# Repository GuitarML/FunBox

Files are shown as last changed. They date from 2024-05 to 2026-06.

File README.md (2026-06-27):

# Funbox


Funbox is a digital stereo guitar effect platform using the Daisy Seed by Electrosmith.
This repo includes the KiCad design files for the PCB, as well as software packages to configure your
Funbox as a fully featured guitar pedal. You can build your own and use the effects included here,
or use it as a starting place to design your own awesome pedal!

Video Demos on YouTube:

[Mars Amp Sim/Delay](https://youtu.be/e60Wy_VvJX8?si=AbR1MXqZ35HZ0Mvu), [Jupiter Reverb Shaper](https://youtu.be/iQnR0dN56QY?si=inZRtJW6ivPTOBN7),
[Neptune Reverb/Delay](https://youtu.be/nuLmwTXF1v8?si=5k8mRED5zVJWO6t1), [Pluto Dual Looper](https://youtu.be/xCFR0EeIMSg?si=6pakTC9j9leRP9t6),
[Venus Spectral Reverb](https://youtu.be/IHFEQsWR4W4?si=BbFsI6RXE-6vq7Sy), [Saturn Spectral Delay](https://youtu.be/adQQrBSwXU4?si=lk55HOxCmDiPBn_s),
[MidiKeys Synth](https://youtu.be/qRBMoK8jLx0?si=yauST03D38Y4MzrH), [Mercury Amp Emulator](https://youtu.be/-yD2pLMCNi4?si=rLxFXH2HT4IHW6-g),
[Earth Plate Reverb/Octave](https://youtu.be/5oxMYXyyZHo?si=3_w1OVgaGqCgooyH) [Uranus Granular Delay and Synth](https://youtu.be/lxxZvYDoElI?si=sbfe8fWKY_A6ajux)

Read the [Funbox Build Guide](https://medium.com/@keyth72/funbox-build-guide-afbd8046121e) for a step by step on ordering parts, soldering and assembling the pcb and hardware, and uploading programs to the Funbox.

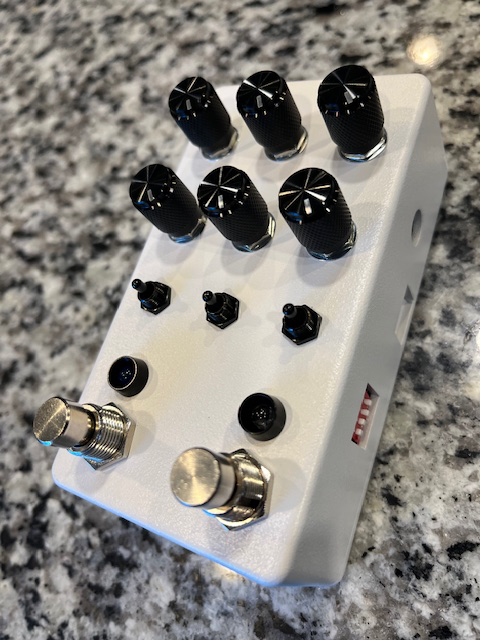
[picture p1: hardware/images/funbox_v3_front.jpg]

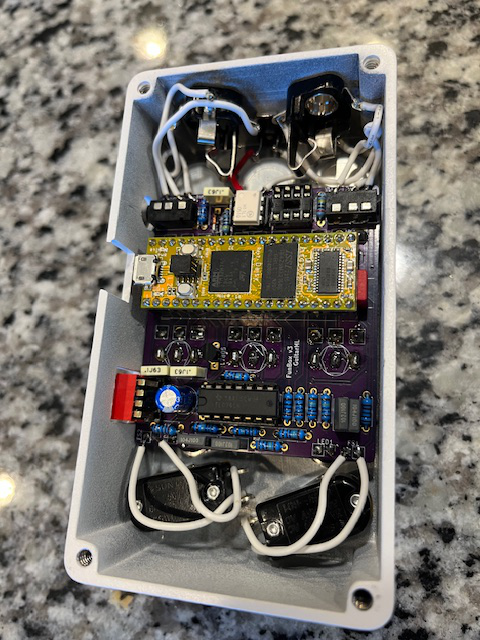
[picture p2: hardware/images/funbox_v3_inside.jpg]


The resources included here allow you to build a guitar pedal with comparable features to commercial brands. 
Soldering is required to build the hardware. Tayda drill templates are linked along with an Adobe Illustrator 
template for UV printing the enclosure, if desired. 

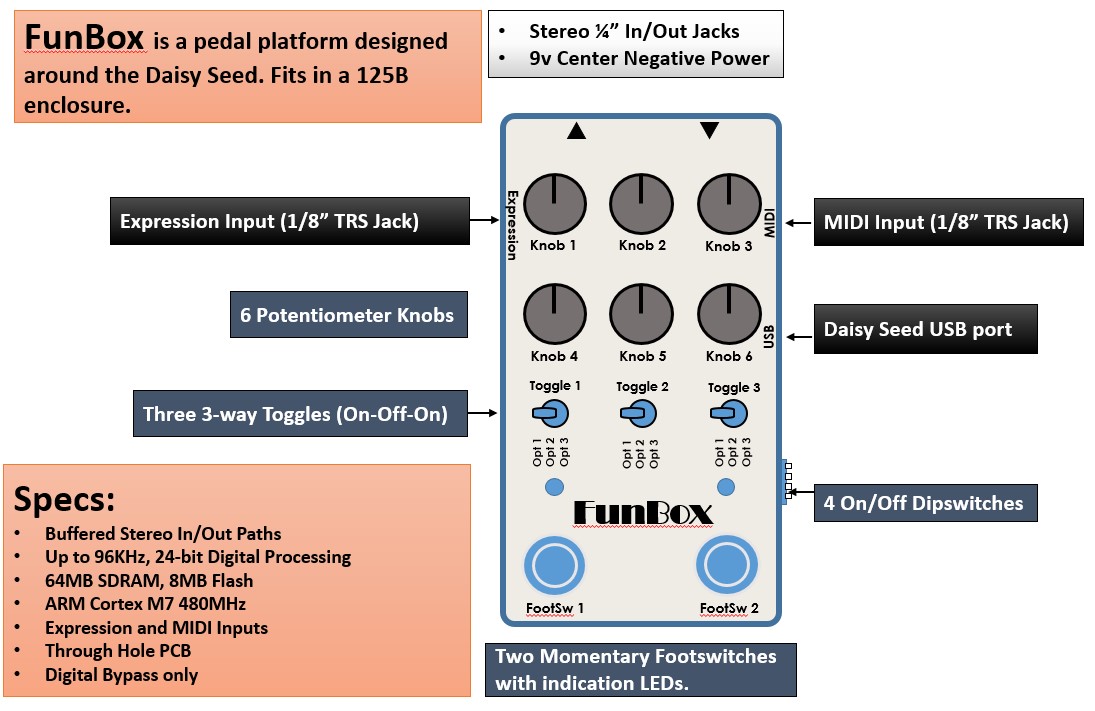
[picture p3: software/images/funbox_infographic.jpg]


## Hardware

The Funbox pedal consists of the following main components:

 - Daisy Seed (order from [Electro-Smith](https://www.electro-smith.com/)) - $30
 - Funbox PCB (order from OSHPark or other manufacturer) - $30 for minimum of 3 from OshPark
 - 125B Enclosure ([Powder coat](https://www.taydaelectronics.com/cream-125b-style-aluminum-diecast-enclosure.html), [Custom Drill](https://www.taydaelectronics.com/125b-custom-drill-enclosure-service.html), and [UV print](https://www.taydaelectronics.com/125b-uv-printing-service.html) ordered from [Tayda](https://www.taydaelectronics.com/)) - $15
 - Electronic Components (Tayda, Mouser, Amazon, Digikey (for Dipswitches) etc.)
 - Hardware Components for Funbox (1/4" Stereo Audio Jacks, Power Jack, Knobs, Switches) (I like [LoveMySwitches](https://lovemyswitches.com/))
 - "Funbox" Software - Build your own binary from this repo or download .bin from the [Releases page](https://github.com/GuitarML/FunBox/releases)
<br><br>
There are alot of variables in building your own pedal, but typically the Funbox will cost around $120 to $150 to build.

IMPORTANT: If you use the Drill Template, double check that the hole diameters match your components. Especially for the LED's, which use the larger diameter hole for 5mm [LED Bezel](https://lovemyswitches.com/5mm-chrome-metal-led-bezel-bag-of-5/).

The PCB design KiCad is provided [here](https://github.com/GuitarML/Funbox/blob/main/hardware/funbox_v3_midi_exp), which can be used to order from a manufacturer such as OSHPark or PCBWay.<br>
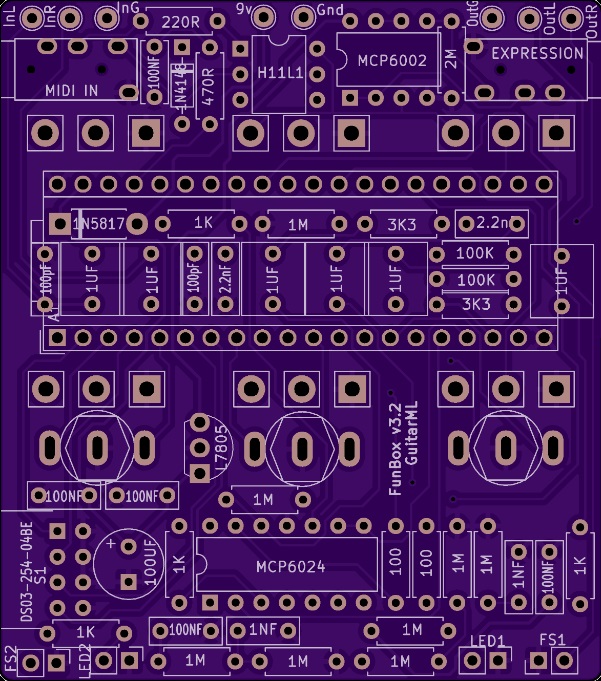
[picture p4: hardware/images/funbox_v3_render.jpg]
<br>
Component values are printed on the board for easy assembly! (OSHPark render shown here)

## Software

The following pedal modules are provided here:

Planet Series
- [Mercury](https://github.com/GuitarML/Mercury): An amp emulator running NAM Neural Amp Modeler and a 4 band EQ.
- [Venus](https://github.com/GuitarML/Funbox/blob/main/software/Venus): A Spectral Reverb using a FFT to create shimmery, ethereal soundscapes.
- [Earth](https://github.com/GuitarML/Earth): A Plate Reverb with octave and overdrive effects.
- [Mars](https://github.com/GuitarML/Funbox/blob/main/software/Mars): An amp sim/delay using neural models and Impulse Responses and three delay modes.
- [Jupiter](https://github.com/GuitarML/Funbox/blob/main/software/Jupiter): A Reverb with a focus on EQ for shaping the sound.
- [Saturn](https://github.com/GuitarML/Funbox/blob/main/software/Saturn): A Spectral delay using a FFT to delay different frequencies individually.
- [Uranus](https://github.com/GuitarML/Funbox/blob/main/software/Uranus): A granular delay and FM synth.
- [Neptune](https://github.com/GuitarML/Funbox/blob/main/software/Neptune): A Reverb/Delay capable of ethereal sounds.
- [Pluto](https://github.com/GuitarML/Funbox/blob/main/software/Pluto): A Dual/Stereo looper with variable speed/direction control and real time loop effects.

There are also a couple [Experiments](https://github.com/GuitarML/Funbox/blob/main/software/Experiments) including a Chorus/Reverb and FFT based filter.

Download the compiled modules for the Funbox from the [Releases Page](https://github.com/GuitarML/FunBox/releases).

### Build the Software
Head to the [Electro-Smith Wiki](https://github.com/electro-smith/DaisyWiki) to learn how to set up the Daisy environment on your computer.

```
# Clone the repository
$ git clone https://github.com/GuitarML/Funbox.git
$ cd Funbox

# initialize and set up submodules
$ git submodule update --init --recursive

# Build the daisy libraries (after installing the Daisy Toolchain):
# Replace the daisy_petal files in libDaisy/src with the files in the "mod" directory to properly map controls on Funbox.
$ make -C libDaisy
$ make -C DaisySP

# Build the desired pedal firmware (Mars pedal shown below as example) (after installing the Daisy Toolchain)
$ cd software/Mars
$ make
```

Then upload the firmware (.bin) to your Funbox pedal with the following commands (or use the [Electrosmith Web Programmer](https://electro-smith.github.io/Programmer/))
```
# This is the procedure for uploading to Flash memory on the Daisy Seed, if using SRAM memory use Bootloader method (Mars and Neptune use SRAM).
cd your_pedal
# using USB (after entering bootloader mode)
make program-dfu
# using JTAG/SWD adaptor (like STLink)
make program
```

To upload your firmware to SRAM (more memory available here for larger programs), see the [libdaisy Bootloader Reference](https://electro-smith.github.io/libDaisy/md_doc_2md_2__a7___getting-_started-_daisy-_bootloader.html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)
or use the [Electrosmith Web Programmer](https://electro-smith.github.io/Programmer/)

To use the Electrosmith Web Programmer to upload programs to SRAM (480KB available instead of 128KB in Flash), do this:
1. Connect to the Daisy Seed as normal from the [Electrosmith Web Programmer](https://electro-smith.github.io/Programmer/).
2. Click "Advanced" button at the bottom, and click "Flash Bootloader Image".
3. On the Daisy Seed, press the RESET button (LED should be lit), and then quickly press the BOOT button. The BOOT LED should now be pulsing.
4. Back in the Web Programmer, choose your .bin file from the "Choose File" button, and then click the "Program" button to upload to SRAM.
5. To load a program back to Flash after using the Bootloader, do the normal upload procedure to overwrite the Bootloader with your new program.

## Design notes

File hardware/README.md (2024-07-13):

# Hardware

This directory contains the KiCad files for manufacturing the Funbox PCB. Includes schematic, pcb, and generated BOM.
Funbox uses a 125B sized enclosure.

## Funbox v1

VERIFIED WORKING - using OshPark standard board manufacturing

Funbox v1 uses a 125B enclosure with the following features:
- Stereo In/Out
- 9v power
- 6 potentiometer knobs 
- 3 3-way switches On-Off-On
- 2 SPST momentary footswitches
- 2 LEDs
- 2 Dipswitches

[Tayda Drill Template](https://drill.taydakits.com/box-designs/new?public_key=bXVVdnZXK0pOVWJjZG5YOGtwd282Zz09Cg==)

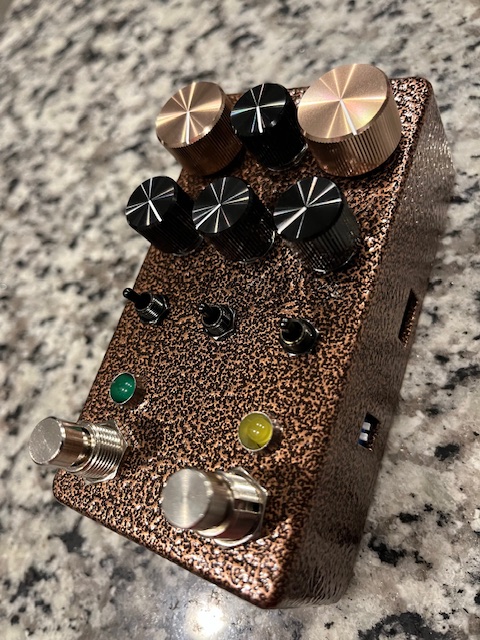
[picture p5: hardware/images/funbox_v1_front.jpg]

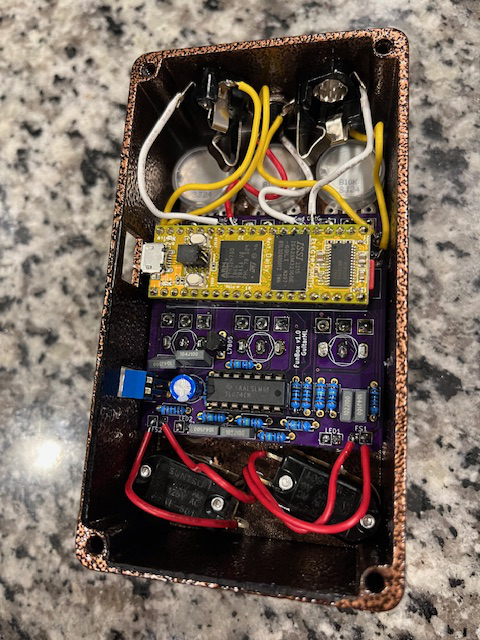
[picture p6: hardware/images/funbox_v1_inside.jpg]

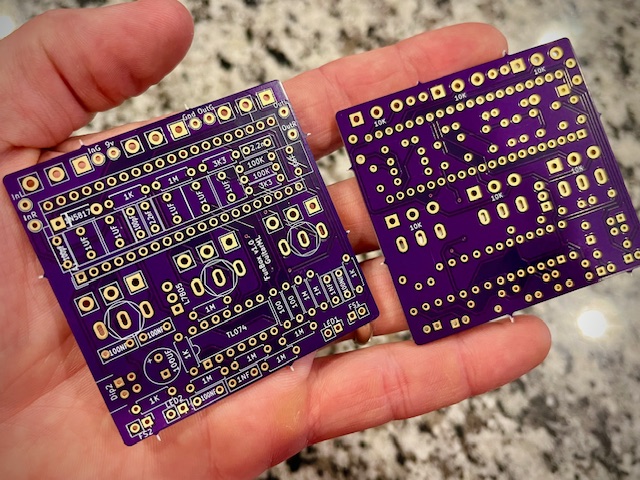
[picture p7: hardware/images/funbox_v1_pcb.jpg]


## Funbox v2

Funbox v2 adds MIDI In/Out via two 1/8" TRS jacks and up to a 4 dip switch array, instead of 2.

[Tayda Drill Template](https://drill.taydakits.com/box-designs/new?public_key=M3BDZTdRSmFWRkF4QXpQUzRORjIwQT09Cg==)

CURRENTLY UNTESTED 

## Funbox v3.2

Funbox v3 replaces the MIDI out jack from version 2 with an Expression Input jack. 
Version 3.2 replaces the TL072 Quad Op Amp with a MCP6024 for reduced noise.
Note: Since most Expresion pedals use 1/4" TRS cables, an adapter is required (Female 1/4" to Male 1/8" stereo adapter, or 1/4" to 1/8" TRS cable.)

[Tayda Drill Template](https://drill.taydakits.com/box-designs/new?public_key=M3BDZTdRSmFWRkF4QXpQUzRORjIwQT09Cg==) (Same as version 2)

The Gerber files used for ordering from PCBway have been added in GerberSeed_PCBway_Funbox_v3p2.zip (note that other manufacturers may have different Gerber requirements)

The Funbox v3.2 board is a shared project on OSHPark, click [here](https://oshpark.com/shared_projects/MnthZS4N) to go to the project page for easy ordering.

VERIFIED WORKING

Funbox v3 uses a 125B enclosure with the same features a version 1 with the following additions:
- Midi Input from a 1/8 inch TRS jack
- Expression Input from a 1/8 inch TRS jack
- 4 Dipswitches

app
app

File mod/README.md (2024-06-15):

# libDaisy Modifications

Replace these files in libDaisy before building libDaisy. This is required to correctly map the controls for Funbox hardware.
Applicable for Funbox v1, v2, and v3 PCBs.
<br><br>
INSTRUCTIONS:
```
# Replace libDaisy/src/daisy_pedal.h with Funbox/mod/daisy_pedal.h
# Replace libDaisy/src/daisy_pedal.cpp with Funbox/mod/daisy_pedal.cpp

make -C libDaisy
```

## bksheperd hardware module definitions

These are the hardware definitions for using the bksheperd guitar pedal framework on the Funbox. 
Add these two files to the following location in your [DaisySeedProjects](https://github.com/bkshepherd/DaisySeedProjects/tree/main) repo and update 
the guitar_pedal.cpp to use this hardware definition.

Add the guitar_pedal_funbox.h and guitar_pedal_funbox.cpp file to this location to use this extensive guitar effect framework on the Funbox:
https://github.com/bkshepherd/DaisySeedProjects/tree/main/Software/GuitarPedal/Hardware-Modules

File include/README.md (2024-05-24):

# Include
This contains the funbox.h header along with custom headers for Funbox software.

## Contents
 - expressionHandler: Expression pedal code for the Funbox v3 board. Remaps knob controls to use with an expression pedal.

 - funbox.h : Include header file for Funbox. Applicable for Funbox version 1, version 2, and version 3. This provides an abstraction for the knobs, switches, and LEDs when writing software for Funbox.```

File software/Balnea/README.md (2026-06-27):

# Balnea

Balnea is a digital delay and pitch shifter inspired by the CBA Thermae pedal.

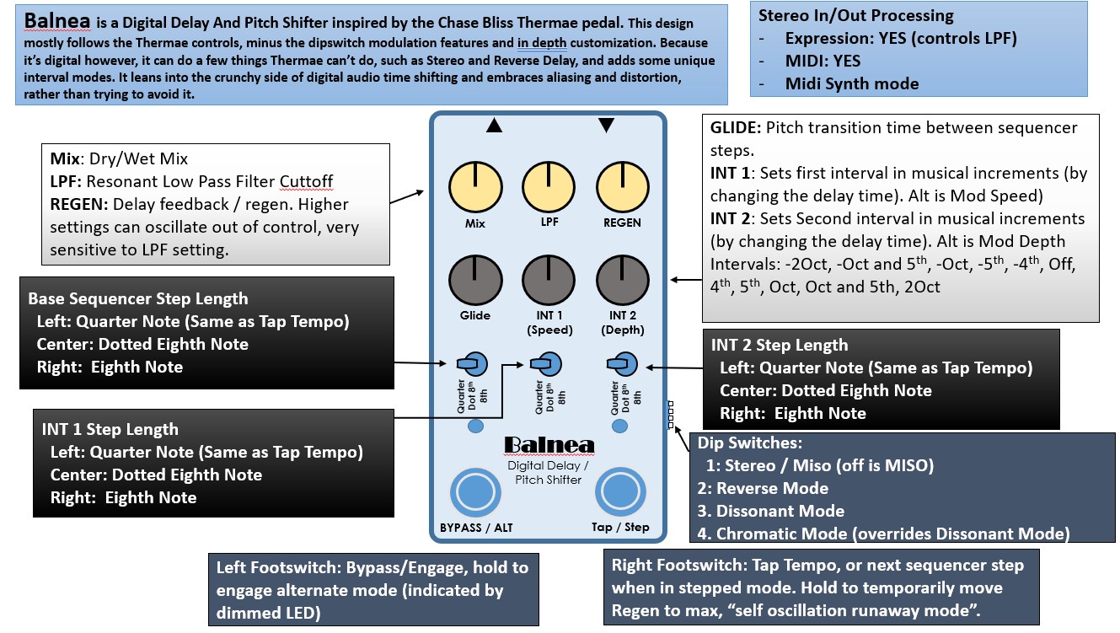
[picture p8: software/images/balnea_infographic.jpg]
app


## Controls
See infographic

### MIDI Reference

Midi Keyboard notes only, Midi knob control TBD

## Build

Build with ```make``` after installing the Daisy Toolchain.

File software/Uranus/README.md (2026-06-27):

# Uranus

Uranus is a Granular delay and synth. It splits your guitar signal (or anything else) into 
small grains of audio that can be manipulated to create atmospheric soundscapes. It features a monophonic
granular synth mode and a polyphonic FM synthesizer with controllable parameters over Midi.

Uranus uses a modified version of the GranularPlayer class in DaisySP.

## Controls

| Control | Description | Comment |
| --- | --- | --- |
| Ctrl 1 | Size | Grain size 1ms to 300ms |
| Ctrl 2 | Mix (Alt Stereo Spread) | Dry/Wet Mix, or alternate mode Stereo spread of each individual grain |
| Ctrl 3 | Pitch (Alt pitch LFO Depth) | Pitch (transposition) of the grains, -1 to +1 octave in semitones |
| Ctrl 4 | Feedback | Feedback of the delayline |
| Ctrl 5 | Width | The width of time that grains can be randomly sampled from (0 to 50ms). Turn down for more a concise sound, turn up to sample a wider range of the audio  |
| Ctrl 6 | Speed (Alt pitch LFO Rate) | Speed of grain playback -2x to +2x |
| 3-Way Switch 1 | Grain Mode | left=Oct up mid=oct down right=oct up and oct down |
| 3-Way Switch 2 | Grain Envelope | left= smooth cosine envelope for each grain  mid= slow attack linear envelope  right=fast attack linear envelope |
| 3-Way Switch 3 | Synth Mode | left=none (only taking audio input)  mid=granular synth mode (puts an ADSR envelope over the current granular effect, triggered by a midi keyboard and transposed from middle C) right=FM Synth (blocks audio in, use midi for polyphonic, 2 operator FM synthesizer) |
| Dip Switch 1 | N/A |  |
| Dip Switch 2 | N/A |  |
| Dip Switch 3 | N/A |  |
| Dip Switch 4 | N/A |  |
| FS 1 | Bypass | Effect bypass or hold for Alternate mode |
| FS 2 | Hold Sample | Holds the current delay buffer (latching), blocks overwriting |
| LED 1 | Bypass/Alt Indicator | Dims LED while footswitch held in alt mode |
| LED 2 | Hold Indicator | On when in Hold mode|
| Audio In 1 | Mono In | Ignores Right channel input  |
| Audio Out 1 | Stereo | Stereo Out |

### Expression
1. Plug in passive expression pedal into the 1/8" jack on the top left side of pedal. (will need a 1/4" female to 1/8" male TRS adapter)<br>
2. Hold both footswitches until they both light up (more than 0.5 seconds, but less than 2 seconds), you are now in Set Expression mode.<br>
3. Move the expression pedal into the heel position (up) and move any number of knobs to where you want to heel limit to be (for example you could turn Volume down). The right LED should be brighter up to indicate the heel position is ready to set.*<br>
3. Move the expression pedal into the toe position (down) and move any number of knobs to where you want to toe limit to be (for example you could turn Volume up). The Left LED should be brighter to indicate the toe position is ready to set.*<br>
4. Hold both footswitches to exit Set Expression mode. This will activate expression for the moved knobs. The moved knobs will be inactive until Expression Mode is deactivated.<br>
5. Repeat step 2 to reset Expression knobs.<br>
6. Hold both footswitches for 2 seconds or more to clear any Expression action and give control back to the Funbox knobs.<br>
<br>
* Currently, the expression input requires the full range of the expression pedal, in order to detect Up/Down positions. You can sometimes trim the expression pedal to not use the full range, so adjust the trim as necessary.<br>
  Also, some expression pedals have a "Standard" or "Alternate/Other" mode. Funbox should work on the "Standard" mode.<br>

### MIDI Reference

| Control | MIDI CC | Value |
| --- | --- | --- |
| Knob 1 | 14 | 0- 127 |
| Knob 2 | 15 | 0- 127 |
| Knob 3 | 16 | 0- 127 |
| Knob 4 | 17 | 0- 127 |
| Knob 5 | 18 | 0- 127 |
| Knob 6 | 19 | 0- 127 |

FM Synth Parameters over MIDI

| Control | MIDI CC | Value |
| --- | --- | --- |
| Carrier Level (overall volume) | 20 | 0- 127 |
| Carrier Ratio (0.5 to 16.5 in 0.5 increments) | 21 | 0- 127 |
| Modulator Level | 22 | 0- 127 |
| Modulator Ratio (0.5 to 16.5 in 0.5 increments) | 23 | 0- 127 |
| Modulator Envelope Attack | 24 | 0- 127 |
| Modulator Envelope Decay  | 25 | 0- 127 |
| Modulator Envelope Sustain| 26 | 0- 127 |
| Modulator Envelope Release| 27 | 0- 127 |
| Carrier Envelope Attack  | 28 | 0- 127 |
| Carrier Envelope Decay | 29 | 0- 127 |
| Carrier Envelope Sustain | 30 | 0- 127 |
| Carrier Envelope Release | 31 | 0- 127 |

Granular Synth Parameters over MIDI (uses the same MIDI CC as FM Carrier Envelope, based on Synth Mode Toggle)

| Control | MIDI CC | Value |
| --- | --- | --- |
| Envelope Attack  | 28 | 0- 127 |
| Envelope Decay | 29 | 0- 127 |
| Envelope Sustain | 30 | 0- 127 |
| Envelope Release | 31 | 0- 127 |

## Build

Uranus runs in Flash memory on the Daisy Seed.

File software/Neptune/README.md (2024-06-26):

# Neptune (Planet Series)

Neptune is a Stereo Reverb/Delay pedal. The reverb used here is from the [CloudSeed plugin](https://github.com/ValdemarOrn/CloudSeed) (MIT License), and the Delay includes normal, octave, and reverse modes.
Neptune is very similar to the GuitarML Atlas pedal. The reverse delay is a modified version of the reverse delay from [Veno-Echo](https://github.com/AdamFulford/Veno-Echo) (MIT License)

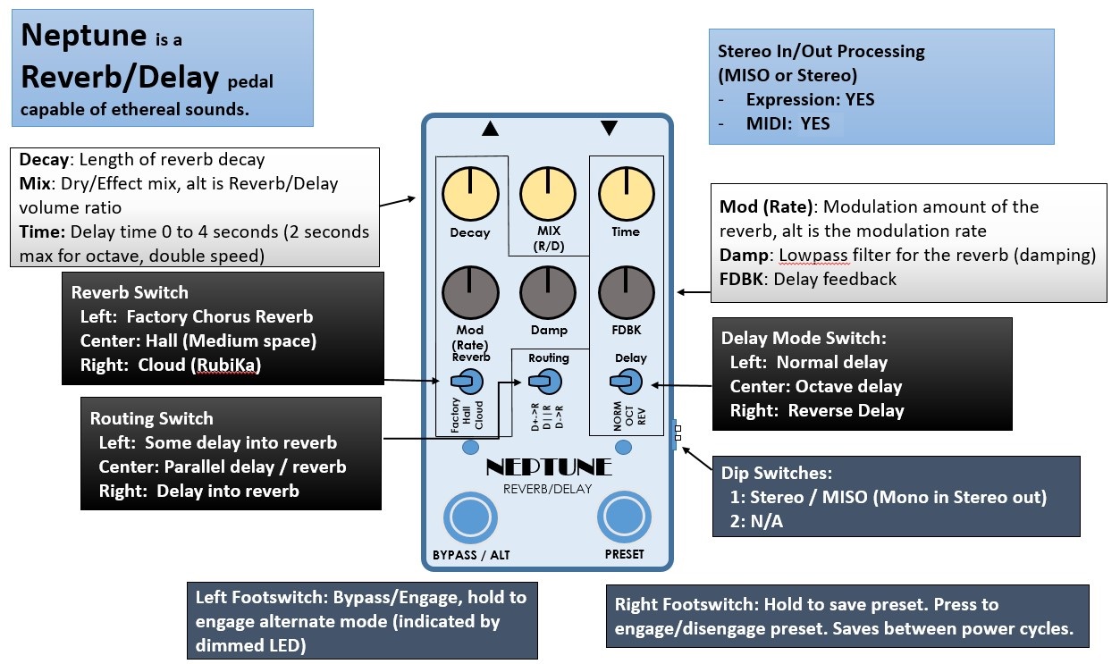
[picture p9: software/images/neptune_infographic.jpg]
app


## Controls

| Control | Description | Comment |
| --- | --- | --- |
| Ctrl 1 | Reverb Decay | Increases the decay time of the reverb |
| Ctrl 2 | Mix (rev/delay mix)  | Mix control between the Dry input and effect, alternate is Reverb/Delay volume ratio |
| Ctrl 3 | Delay Time | Delay time from 0 to 4 seconds |
| Ctrl 4 | Mod (Mod Rate) | Amount of modulation of the reverb, Alternate mode sets is mod rate |
| Ctrl 5 | Reverb LowPass | Delay time 0 to 2 seconds.  |
| Ctrl 6 | Delay Feedback | Delay Feedback (how long delay takes to fade out) |
| 3-Way Switch 1 | Reverb Mode |  left: Factory Chorus, center: Medium Space, right: RubiKai (These mostly match the CloudSeed presets) |
| 3-Way Switch 2 | Routing |  left: Some delay fed to reverb, center: Parallel reverb/delay right: delay into reverb in series |
| 3-Way Switch 3 | Delay Mode | left: normal, center: octave, right: reverse |
| Dip Switch 1 | MISO/Stereo | MISO (Mono in stereo out), or True Stereo |
| Dip Switch 2 |  |  |
| FS 1 | Bypass, hold to put into Alternate mode | Alternate mode indicated by dimmed LED, switches back when let go |
| FS 2 | Preset | Hold to save preset, press to engage/disengage preset. Saves between power cycles. |
| LED 1 | Bypass/Alternate Indicator |  |
| LED 2 | Preset Indicator |  ||
| Audio In 1 | Stereo In | Right channel ignored if MISO Mode turned on |
| Audio Out 1 | Stereo Out  |  |
<br>
### Expression
1. Plug in passive expression pedal into the 1/8" jack on the top left side of pedal. (will need a 1/4" female to 1/8" male TRS adapter)<br>
2. Hold both footswitches until they both light up (more than 0.5 seconds, but less than 2 seconds), you are now in Set Expression mode.<br>
3. Move the expression pedal into the heel position (up) and move any number of knobs to where you want to heel limit to be (for example you could turn Volume down). The right LED should be brighter up to indicate the heel position is ready to set.*<br>
3. Move the expression pedal into the toe position (down) and move any number of knobs to where you want to toe limit to be (for example you could turn Volume up). The Left LED should be brighter to indicate the toe position is ready to set.*<br>
4. Hold both footswitches to exit Set Expression mode. This will activate expression for the moved knobs. The moved knobs will be inactive until Expression Mode is deactivated.<br>
5. Repeat step 2 to reset Expression knobs.<br>
6. Hold both footswitches for 2 seconds or more to clear any Expression action and give control back to the Funbox knobs.<br>
<br>
* Currently, the expression input requires the full range of the expression pedal, in order to detect Up/Down positions. You can sometimes trim the expression pedal to not use the full range, so adjust the trim as necessary.<br>
  Also, some expression pedals have a "Standard" or "Alternate/Other" mode. Funbox should work on the "Standard" mode.<br>

### MIDI Reference

| Control | MIDI CC | Value |
| --- | --- | --- |
| Knob 1 | 14 | 0- 127 |
| Knob 2 | 15 | 0- 127 |
| Knob 3 | 16 | 0- 127 |
| Knob 4 | 17 | 0- 127 |
| Knob 5 | 18 | 0- 127 |
| Knob 6 | 19 | 0- 127 |

## Build

Neptune runs in SRAM memory on the Daisy Seed. You must use the Bootloader to load the executable.
Note: MIDI will not work if you use the Bootloader from the Daisy Web Programmer (it's an old version).

Before building Neptune, you must build Cloudseed with ```make```

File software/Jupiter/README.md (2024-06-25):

# Jupiter (Planet Series)

Jupiter is a Stereo Reverb pedal. The reverb used here is from the [CloudSeed plugin](https://github.com/ValdemarOrn/CloudSeed) (MIT License). It is the same reverb from the Neptune pedal, 
but more EQ controls are exposed to the user, specifically the post reverb low and high shelf filters, both the frequency cutoff and gain.

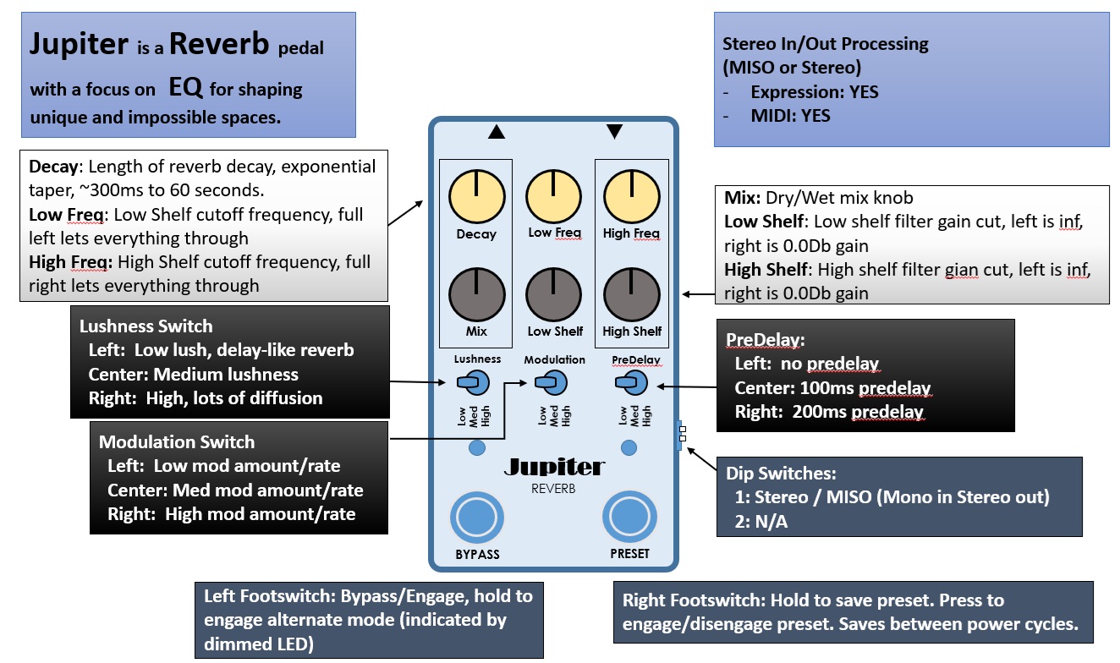
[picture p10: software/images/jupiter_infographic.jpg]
app


## Controls

| Control | Description | Comment |
| --- | --- | --- |
| Ctrl 1 | Reverb Decay | Increases the decay time of the reverb, about 300ms to 60 seconds, exponential taper (noon is 2 seconds decay) |
| Ctrl 2 | Low Shelf Frequency  | Log Taper 20Hz to 1000Hz, noon is about 200Hz |
| Ctrl 3 | High Shelf Frequency  | Log Taper 400 Hz to 20000Hz, noon is about 4300Hz |
| Ctrl 4 | Mix | Dry to Wet mix |
| Ctrl 5 | Low Shelf Gain | Low shelf cut, from 100% cut to 0.0 gain at max knob  |
| Ctrl 6 | High Shelf Gain | High shelf cut, from 100% cut to 0.0 gain at max knob |
| 3-Way Switch 1 | Lush Level | Amount of "Lushness", low, medium, high |
| 3-Way Switch 2 | Modulation Level  |  Sets the modulation amount and rate, low, medium, high  |
| 3-Way Switch 3 | PreDelay | Sets predelay, 0, 100ms, 200ms | 
| Dip Switch 1 | MISO/Stereo | MISO (Mono in stereo out), or True Stereo |
| Dip Switch 2 |  |  |
| Dip Switch 3 |  |  |
| Dip Switch 4 |  |  |
| FS 1 | Bypass/Engage |  |
| FS 2 | Preset | Hold to save preset, press to engage/disengage preset. Saves between power cycles. |
| LED 1 | Bypass Indicator |  |
| LED 2 | Preset Indicator |  |
| Audio In 1 | Stereo In | Right channel ignored if MISO Mode turned on |
| Audio Out 1 | Stereo Out  |  |
<br>
### Expression
1. Plug in passive expression pedal into the 1/8" jack on the top left side of pedal. (will need a 1/4" female to 1/8" male TRS adapter)<br>
2. Hold both footswitches until they both light up (more than 0.5 seconds, but less than 2 seconds), you are now in Set Expression mode.<br>
3. Move the expression pedal into the heel position (up) and move any number of knobs to where you want to heel limit to be (for example you could turn Volume down). The right LED should be brighter up to indicate the heel position is ready to set.*<br>
3. Move the expression pedal into the toe position (down) and move any number of knobs to where you want to toe limit to be (for example you could turn Volume up). The Left LED should be brighter to indicate the toe position is ready to set.*<br>
4. Hold both footswitches to exit Set Expression mode. This will activate expression for the moved knobs. The moved knobs will be inactive until Expression Mode is deactivated.<br>
5. Repeat step 2 to reset Expression knobs.<br>
6. Hold both footswitches for 2 seconds or more to clear any Expression action and give control back to the Funbox knobs.<br>
<br>
* Currently, the expression input requires the full range of the expression pedal, in order to detect Up/Down positions. You can sometimes trim the expression pedal to not use the full range, so adjust the trim as necessary.<br>
  Also, some expression pedals have a "Standard" or "Alternate/Other" mode. Funbox should work on the "Standard" mode.<br>

### MIDI Reference

| Control | MIDI CC | Value |
| --- | --- | --- |
| Knob 1 | 14 | 0- 127 |
| Knob 2 | 15 | 0- 127 |
| Knob 3 | 16 | 0- 127 |
| Knob 4 | 17 | 0- 127 |
| Knob 5 | 18 | 0- 127 |
| Knob 6 | 19 | 0- 127 |

## Build

Before building Jupiter, you must build Cloudseed with ```make``` in the CloudSeed folder.

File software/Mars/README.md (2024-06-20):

# Mars (Planet Series)

Mars is an amp sim / delay pedal. It includes 3 neural models, 3 Impulse Responses (Cab Sim), and a delay effect with dotted 8th and triplett modes.

Neural Network inference for the amp/pedal models uses [RTNeural](https://github.com/jatinchowdhury18/RTNeural)
The Impluse Response code is a modified version of the IR processing in the [NAM plugin](https://github.com/sdatkinson/NeuralAmpModelerPlugin) (MIT License) 

Note: Due to the processing power required for the neural models and IRs, Mars is a mono effect, which on the Funbox pedal is copied left to right channel for output. 
If a stereo signal is going into the input, Mars will only take the left channel for processing.

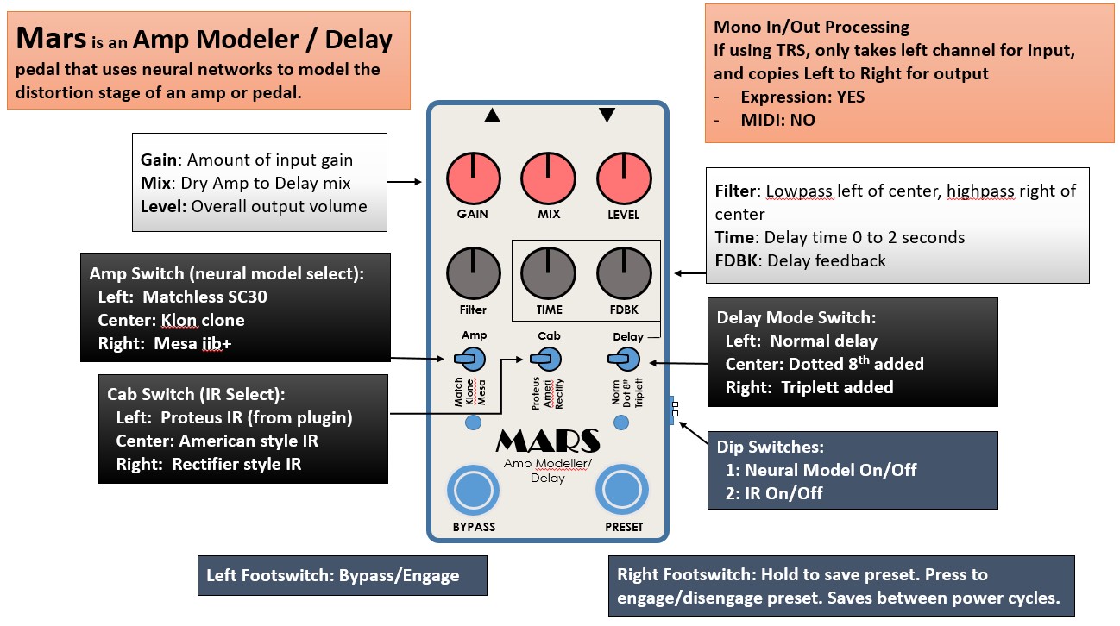
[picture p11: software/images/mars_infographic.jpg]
app


## Controls

| Control | Description | Comment |
| --- | --- | --- |
| Ctrl 1 | Gain | Increases the input gain to the neural model |
| Ctrl 2 | Mix | Mix control between the amp and delay |
| Ctrl 3 | Level | Overall volume output |
| Ctrl 4 | Filter | Lowpass filter left of center, highpass right of center |
| Ctrl 5 | Delay Time | Delay time 0 to 2 seconds.  |
| Ctrl 6 | Delay Feedback | Delay Feedback (how long delay takes to fade out) |
| 3-Way Switch 1 | Amp/Model Select | 3 available models, default: left: Matchless SC30, center: Klon pedal, right: Mesa iib |
| 3-Way Switch 2 | IR Select |  3 available IRs, default: left: Proteus (from GuitarML Proteus plugin), center: American, right: Rectifier |
| 3-Way Switch 3 | Delay Mode | left: normal, center: dotted 8th, right: triplett |
| Dip Switch 1 | Amp On/Off | Engage/Disengage Neural model |
| Dip Switch 2 | IR On/Off| Engage/Disengage IR |
| FS 1 | Bypass |  |
| FS 2 | Preset | Hold to save preset, press to engage/disengage preset. Saves between power cycles. |
| LED 1 | Bypass Indicator |  |
| LED 2 | Preset Indicator |  ||
| Audio In 1 | Mono In (Left Channel) | Right channel ignored if using TRS  |
| Audio Out 1 | Mono Out  | Left channel copied to Right Channel if using TRS |

## Build

Mars runs in SRAM memory on the Daisy Seed. You must use the Bootloader to load the executable.

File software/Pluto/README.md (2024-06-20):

# Pluto

Pluto is a wacky dual/stereo looper for endless experimentation. Each looper features a variable speed control, smooth or stepped,
and several effects and loop modes. Pluto runs at 96kHz instead of 48kHz, in order to have the best quality when slowing down loops,
but don't worry, lots of aliasing/artifacts are present when strethching audio!

Loops are recorded at the current speed setting. For example, if the speed of Loop A is at 2x and you record a loop, it will sound normal, but turning the speed 
knob down to 1x will play your loop at half speed (and half the samplerate). 

Pluto is in active development, more features coming 

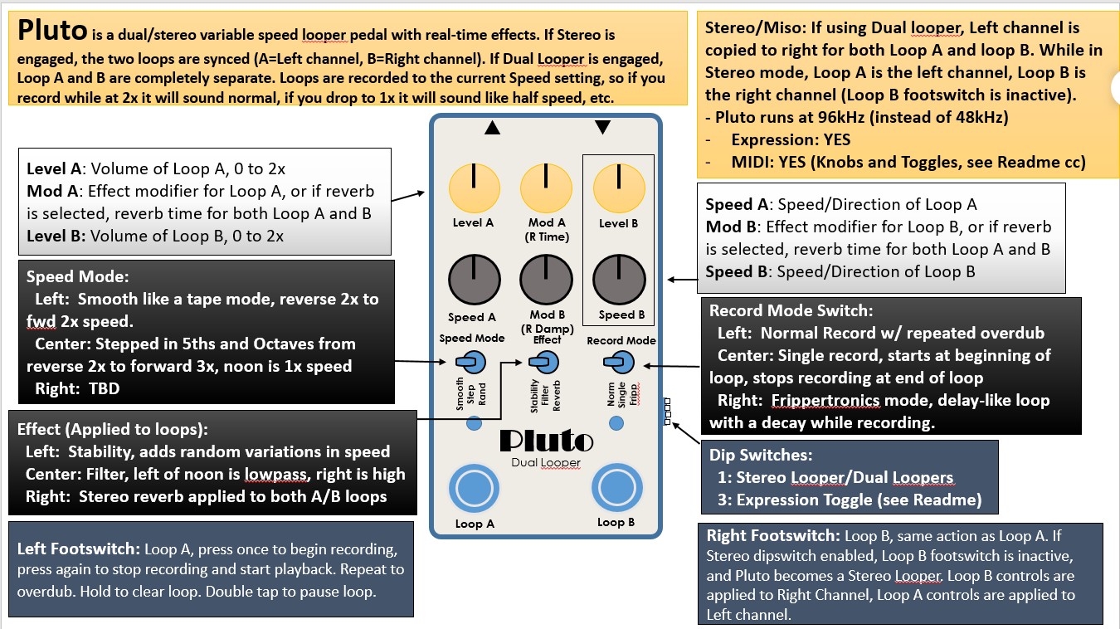
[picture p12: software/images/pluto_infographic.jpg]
app


## Controls

| Control | Description | Comment |
| --- | --- | --- |
| Ctrl 1 | Looper A Volume |  |
| Ctrl 2 | Looper A Modify | Modifies the current effect applied to loop A (or for Reverb, controls decay time) |
| Ctrl 3 | Looper B Volume |  |
| Ctrl 4 | Looper A Speed/Direction | Speed and direction of Loop A, -2x (reverse) to +2x speed, noon is 1x speed |
| Ctrl 5 | Looper A Modify | Modifies the current effect applied to loop A (or for Reverb, controls decay time) |
| Ctrl 6 | Looper B Speed/Direction | Speed and direction of Loop B, -2x (reverse) to +2x speed, noon is 1x speed |  |
| 3-Way Switch 1 | Looper A/B Speed mode | Left = smooth, Center=Stepped, Right= TBD |
| 3-Way Switch 2 | Live effect select (controls what modify knobs do) | Left=Stability(random variations in playback speed), Center=Filter (LP to the left, HP to the right), Right=Reverb (stereo, ModA is decay, ModB is damping) |
| 3-Way Switch 3 | Loop Record Mode | Left = normal, Center = One Time loop record, Right= Frippertronics (when recording, acts like a delay, applying a decay time to the loop) |
| Dip Switch 1 | MISO/Stereo | Miso only takes the left channel input, and treats each looper as independant. Stereo takes L/R input and treats loopers as connected when recording (Looper B footswitch is inactive in Stereo Mode) |
| Dip Switch 2 | TBD | Want to add a Sync mode here, where the loop time for both A/B are equal |
| FS 1 | Loop A control | Tap once to start recording loop, tap again to stop record and start playback. Double tap to pause loop. Hold to clear loop. Tap again to overdub. Currently no undo function. |
| FS 2 | Loop B control | Same as Loop A |
| LED 1 | Loop A Indicator | Pulses while recording, Solid while playback, blinking while paused. |
| LED 2 | Loop B indicator | Same as Loop A|
| Audio In 1 | Stereo (or MISO) | MISO will use 2 speparate loopers, and copy left channel output to right, Stereo will use 1 looper, and loop A is left channel, loop B is right channel |
| Audio Out 1 | Stereo |  |

<br>
### Expression
Expression Operation: NOTE THAT THIS IS DIFFERENT FROM OTHER PLANET PEDALS**<br>
1. Plug in passive expression pedal into the 1/8" jack on the top left side of pedal. (will need a 1/4" female to 1/8" male TRS adapter)<br>
2. Turn on Dipswitch 3 to enter Set Expression mode, both LEDs should light up, you are now in Set Expression mode.<br>
3. Move the expression pedal into the heel position (up) and move any number of knobs to where you want to heel limit to be (for example you could turn Volume down). The right LED should be brighter up to indicate the heel position is ready to set.*<br>
3. Move the expression pedal into the toe position (down) and move any number of knobs to where you want to toe limit to be (for example you could turn Volume up). The Left LED should be brighter to indicate the toe position is ready to set.*<br>
4. Turn off Dipswitch 3 to exit Set Expression mode and enter Expression Active Mode. <br>
5. Flip Dipswitch 3 on and move expression pedal into both up and down positions without turning any knobs. Flip Dipswitch 3 off to clear expression and give control back to knobs.

<br>
* Currently, the expression input requires the full range of the expression pedal, in order to detect Up/Down positions. You can sometimes trim the expression pedal to not use the full range, so adjust the trim as necessary.<br>
  Also, some expression pedals have a "Standard" or "Alternate/Other" mode. Funbox should work on the "Standard" mode.<br>
<br>
** Since Pluto uses the footswitches for looper funtions, the third dip switch is used to enter/exit Set Expression mode. Flip dipswitch 3 without adjusting any knobs to clear expression settings.

### MIDI Reference

| Control | MIDI CC | Value |
| --- | --- | --- |
| Knob 1 | 14 | 0- 127 |
| Knob 2 | 15 | 0- 127 |
| Knob 3 | 16 | 0- 127 |
| Knob 4 | 17 | 0- 127 |
| Knob 5 | 18 | 0- 127 |
| Knob 6 | 19 | 0- 127 |
| Toggle Left | 21 | 0,1:left ; 2, center; 3 or > right |
| Toggle Center | 22 | 0,1:left ; 2, center; 3 or > right |
| Toggle Right| 23 | 0,1:left ; 2, center; 3 or > right |

## Build

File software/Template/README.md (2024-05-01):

# Pedal

## Controls

| Control | Description | Comment |
| --- | --- | --- |
| Ctrl 1 |  |  |
| Ctrl 2 |  |  |
| Ctrl 3 |  |  |
| Ctrl 4 |  |  |
| Ctrl 5 |  |  |
| Ctrl 6 |  |  |
| 3-Way Switch 1 |  |  |
| 3-Way Switch 2 |  |  |
| 3-Way Switch 3 |  |  |
| Dip Switch 1 |  |  |
| Dip Switch 2 |  |  |
| FS 1 |  |  |
| FS 2 |  |  |
| LED 1 |  |  |
| LED 2 |  | |
| Audio In 1 |  | |
| Audio Out 1 |  |  |

## Build

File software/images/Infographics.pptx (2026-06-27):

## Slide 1

Mars is an Amp Modeler / Delay pedal that uses neural networks to model the distortion stage of an amp or pedal.

Mono In/Out Processing
If using TRS, only takes left channel for input, and copies Left to Right for output
- Expression: YES
- MIDI: NO

Filter: Lowpass left of center, highpass right of center
Time: Delay time 0 to 2 seconds
FDBK: Delay feedback

Gain: Amount of input gain
Mix: Dry Amp to Delay mix
Level: Overall output volume

MARS

Amp Modeller/
Delay

GAIN

MIX

LEVEL

Amp Switch (neural model select):
Left: Matchless SC30
Center: Klon clone
Right: Mesa iib+

Filter

TIME

FDBK

Delay Mode Switch:
Left: Normal delay
Center: Dotted 8th added
Right: Triplett added

Dip Switches:
1: Neural Model On/Off
2: IR On/Off

Right Footswitch: Hold to save preset. Press to engage/disengage preset. Saves between power cycles.

Amp

Match
Klone
Mesa

Cab

Proteus
Ameri
Rectify

Delay

Norm
Dot 8th
Triplett

Cab Switch (IR Select):
Left: Proteus IR (from plugin)
Center: American style IR
Right: Rectifier style IR

BYPASS

PRESET

Left Footswitch: Bypass/Engage

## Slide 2

Neptune is a Reverb/Delay pedal capable of ethereal sounds.

Stereo In/Out Processing
(MISO or Stereo)
- Expression: YES
- MIDI: YES

Decay: Length of reverb decay
Mix: Dry/Effect mix, alt is Reverb/Delay volume ratio
Time: Delay time 0 to 4 seconds (2 seconds max for octave, double speed)

NEPTUNE

REVERB/DELAY

Time

FDBK

Delay

NORM
OCT
REV

Decay

Mod (Rate): Modulation amount of the reverb, alt is the modulation rate
Damp: Lowpass filter for the reverb (damping)
FDBK: Delay feedback

Reverb Switch
Left: Factory Chorus Reverb
Center: Hall (Medium space)
Right: Cloud (RubiKa)

Damp

MIX
(R/D)

Mod
(Rate)

Reverb

Delay Mode Switch:
Left: Normal delay
Center: Octave delay
Right: Reverse Delay

Dip Switches:
1: Stereo / MISO (Mono in Stereo out)
2: N/A

Right Footswitch: Hold to save preset. Press to engage/disengage preset. Saves between power cycles.

Routing

D+->R
D||R
D->R

Routing Switch
Left: Some delay into reverb
Center: Parallel delay / reverb
Right: Delay into reverb

Factory
Hall
Cloud

BYPASS / ALT

PRESET

Left Footswitch: Bypass/Engage, hold to engage alternate mode (indicated by dimmed LED)

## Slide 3

Jupiter is a Reverb pedal with a focus on EQ for shaping unique and impossible spaces.

Decay: Length of reverb decay, exponential taper, ~300ms to 60 seconds.
Low Freq: Low Shelf cutoff frequency, full left lets everything through
High Freq: High Shelf cutoff frequency, full right lets everything through

Lushness Switch
Left: Low lush, delay-like reverb
Center: Medium lushness
Right: High, lots of diffusion

Modulation Switch
Left: Low mod amount/rate
Center: Med mod amount/rate
Right: High mod amount/rate

Left Footswitch: Bypass/Engage, hold to engage alternate mode (indicated by dimmed LED)

Stereo In/Out Processing
(MISO or Stereo)
- Expression: YES
- MIDI: YES

Jupiter

Decay

Mix

Lushness

High Freq

High Shelf

PreDelay

Low Freq

Mix: Dry/Wet mix knob
Low Shelf: Low shelf filter gain cut, left is inf, right is 0.0Db gain
High Shelf: High shelf filter gian cut, left is inf, right is 0.0Db gain

PreDelay:
Left: no predelay
Center: 100ms predelay
Right: 200ms predelay

Dip Switches:
1: Stereo / MISO (Mono in Stereo out)
2: N/A

Right Footswitch: Hold to save preset. Press to engage/disengage preset. Saves between power cycles.

Low Shelf

Low
Med
High

Modulation

Low
Med
High

REVERB

Low
Med
High

BYPASS

PRESET

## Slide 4

Pluto is a dual/stereo variable speed looper pedal with real-time effects. If Stereo is engaged, the two loops are synced (A=Left channel, B=Right channel). If Dual Looper is engaged, Loop A and B are completely separate. Loops are recorded to the current Speed setting, so if you record while at 2x it will sound normal, if you drop to 1x it will sound like half speed, etc.

Stereo/Miso: If using Dual looper, Left channel is copied to right for both Loop A and loop B. While in Stereo mode, Loop A is the left channel, Loop B is the right channel (Loop B footswitch is inactive).
- Pluto runs at 96kHz (instead of 48kHz)
- Expression: YES
- MIDI: YES (Knobs and Toggles, see Readme cc)

Speed A: Speed/Direction of Loop A
Mod B: Effect modifier for Loop B, or if reverb is selected, reverb time for both Loop A and B
Speed B: Speed/Direction of Loop B

Record Mode Switch:
Left: Normal Record w/ repeated overdub
Center: Single record, starts at beginning of loop, stops recording at end of loop
Right: Frippertronics mode, delay-like loop with a decay while recording.

Dip Switches:
1: Stereo Looper/Dual Loopers
3: Expression Toggle (see Readme)

Right Footswitch: Loop B, same action as Loop A. If Stereo dipswitch enabled, Loop B footswitch is inactive, and Pluto becomes a Stereo Looper. Loop B controls are applied to Right Channel, Loop A controls are applied to Left channel.

Level A: Volume of Loop A, 0 to 2x
Mod A: Effect modifier for Loop A, or if reverb is selected, reverb time for both Loop A and B
Level B: Volume of Loop B, 0 to 2x

Speed Mode:
Left: Smooth like a tape mode, reverse 2x to fwd 2x speed.
Center: Stepped in 5ths and Octaves from reverse 2x to forward 3x, noon is 1x speed
Right: TBD

Effect (Applied to loops):
Left: Stability, adds random variations in speed
Center: Filter, left of noon is lowpass, right is high
Right: Stereo reverb applied to both A/B loops

Pluto

Dual Looper

Level A

Speed A

Level B

Speed B

Mod A
(R Time)

Mod B
(R Damp)

Effect

Stability
Filter
Reverb

Speed Mode

Smooth
Step
Rand

Record Mode

Norm
Single
Fripp

Loop A

Loop B

Left Footswitch: Loop A, press once to begin recording, press again to stop recording and start playback. Repeat to overdub. Hold to clear loop. Double tap to pause loop.

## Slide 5

Venus is a Spectral Reverb pedal that operates in the frequency domain to create lush soundscapes. Features string-like overtones, detuning, and spectral freeze.

Decay: Length of decay time
Mix: Dry/Wet Mix
Damp: Amount of Dampening

Shimmer Mode Toggle
Left: Adds Octave Down
Center: Adds Octave Up
Right: Both Octave Up and Down

Mono In/Out Processing
If using TRS, only takes left channel for input, and copies Left to Right for output
- Expression: YES
- MIDI: YES

Shimmer: Adds octave string-like shimmer based on Shimmer mode toggle
Tone: Adds octave + 5ths string-like shimmer
Detune: Right of noon shifts reverb pitch up over time, Left of noon shifts reverb pitch down over time, center is no detuning

Drift Toggle: Oscillates all the knob controls (except mix) between the current setting and 0 at a slow rate ( between 25 and 50 second periods).
Left: Slow drift, Sine wave, lower rate
Center: No drift
Right: More drift, Triangle wave, higher rate

Dip Switches:
1,2,3,4: TBD (no action currently assigned to dip switches)

Right Footswitch: Hold to Freeze the current reverb sound indefinitely.

Venus

Spectral Reverb

Decay

Mix

Damp

Shimmer

Tone

Detune

Shim Mode

-OCT
+OCT
Both

LoFi Mode

Less
None
More

Drift

Less
None
More

LoFi Mode Toggle:
Left: Less applies some samplerate reduction with a lowpass filter
Center: None – no samplerate reduction
Right: More applies more samplerate reduction without a lowpass filter

Left Footswitch: Bypass/Engage, hold more than a half second to enter/exit Set Expression mode. Hold for > 2 seconds to clear all expression settings.

BYPASS

FREEZE

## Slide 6

Saturn is a Spectral Delay pedal that splits your signal into frequency particles and delays each part separately. Like a prism refracting white light into colors, Saturn turns your guitar into a kaleidoscope of sounds.

Stereo In/Out Processing
Mono, MISO, and Stereo modes
- Expression: YES
- MIDI: YES

Time: Up to 4 second delay spread of the individual frequency bins.
FDBK: Feedback of the delay, behavior depends on the mode toggle.
DriftMod: Frequency of drift (0 to 1Hz)

PreDelay: Up to 2 seconds of predelay prior to spectral delay
Mix: Dry/Wet Mix
Filter: Low Pass to the left, Highpass to the right, applied to the delaylines

Saturn

Spectral Delay

PreDelay

Mix

Filter

Time Mode Toggle:
Left: Linear increase in delay from low to high frequencies
Center: Sine wave over low to high frequencies
Right: Random delay times for each frequency

Time

Time Mode

Rand

FDBK

FDBK Mode

Rand

DriftMod

Drift Toggle (slow modulation of all the knobs excluding mix, from the current position to 0) :
Left: Predelay not included in drift modulation
Center: No Drift
Right: Adds Predelay to drift (wacky time stretching sounds)

Drift

Mode1
None
Mode2

Feedback Mode Toggle:
Left: Even, all delaylines have the same fdbk
Center: linear decrease with frequency
Right: Random FDBK values for each freq.

Left Footswitch: Bypass/Engage, hold both footswitches more than a half second to enter/exit Set Expression mode. Hold both footswitches for > 2 seconds to clear all expression settings.

BYPASS

PRESET

Dip Switches:
1: Mono/Stereo (mono processes more freqs)
2: MISO (mono in stereo out) / Stereo
3: Stereo Spread Off/On
4: Adds Feedback to Predelay

Right Footswitch: Hold to save preset of all knobs, toggles, and dipswitches. Press to engage/disengage preset. Saves between power cycles.

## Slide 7

Mercury is an Amp Emulator using Neural Amp Modeler (NAM).

Gain: Amount of input gain
Level: Overall output volume
Presence: +10/-10 dB

Mono In/Out Processing
If using TRS, only takes left channel for input, and copies Left to Right for output
- Expression: YES
- MIDI: YES

Mercury

Amp Modeller

GAIN

LEVEL

PRESENCE

Bass: +10/-10 dB
Mid: +10/-10 dB
Treble: +10/-10 dB

*NAM Models
Low Gain:
- Matchless SC30
- Twin Reverb
- Dumble Low Gain (from kit build)
Medium Gain:
- Dumble Higher Gain (from kit build)
- Ethos Tube Pedal
- JCM800 Medium Gain
High Gain:
- Mesa iib
- Splawn
- PRS Archon

Amp Group
Left: Low Gain
Center: Med Gain
Right: High Gain

Model Select (depends on Toggle 1 group selection)*
Left: Amp 1
Center: Amp 2
Right: Amp 3

BASS

MID

TREBLE

Amp

Low
Med
High

Cab

Amp 1
Amp 2
Amp 3

BYPASS

Left Footswitch: Bypass/Engage

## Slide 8

Earth is a digital Plate Reverb pedal with octave effects.

Mono in Stereo Out Processing (MISO)
- Expression: YES
- MIDI: YES

PreDelay: PreDelay up to around 700ms
Mix: Dry/Wet mix
Decay: Amount of decay of the reverb

Earth

PreDelay

Mix

Decay

Mod Depth: Intensity of reverb mod
Mod Rate: Speed of reverb mod
Filter: High and low cut filter in reverb tank.

Footswitch Action:
Left: Freeze (Decay set to 1)
Center: Overdrive the Reverb
Right: Momentary Octave (based on center toggle)

Mod

Mod Rate

Filter

Size Toggle
Left: Small size
Center: Medium size
Right: Big size

Size

Small
Med
Big

Octave

None
OctUp
OctUpDn

Footswitch

Freeze
OD
Oct

Octave Switch
Left: None
Center: Octave Up
Right: Octave Up and Down

Left Footswitch: Bypass/Engage

BYPASS

Plate Reverb/
Octave

Action

Dip Switches:
1: Diffusion Disabled (on to disable input diffusion)
2. Octave only mode (only sends octaves to reverb, no dry, when in octave mode)

Right Footswitch: Do action based on 3rd toggle.

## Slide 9

Uranus is a Granular delay and synth. Think of this pedal as a sound laboratory.

Stereo In/Out Processing
(MISO) Mono in Stereo Out
- Expression: YES
- MIDI: YES
- Two Keyboard Midi Synth modes

Size: Grain size 1 to 300ms
Mix: Dry/Wet Mix (Alt is stereo spread of each grain.)
Pitch: Transposition in semitones, +/- one octave, center is neutral

Uranus

Size

Mix
(Spread)

Pitch
(LFO Depth)

Feedback: Feedback of the delay buffer.
Width: Width of time in which a grain can randomly play from, 1 to 50ms
Speed: Grain speed -2x to 2x, center is 0

Grain Octave Mode
Left: Normal with Oct up
Center: Normal with Oct down
Right: Oct Up and Oct down

Grain Envelope
Left: Cosine
Center: Slow attack-release linear
Right: Fast attack-release linear

Left Footswitch: Bypass/Engage, hold to engage alternate mode (indicated by dimmed LED)

Width

FDBK
(Spread)

Oct Mode

Oct Up
Oct Dn
Up/Dn

Speed
(LFO Rate)

Synth Mode

Synth Mode
Left: Audio input
Center: Granular Monophonic Synth
Right: Polyphonic FM Synth (12 note polyphony)

Dip Switches:
1: N/A 3. N/A
2: N/A 4. N/A

Right Footswitch: Press to keep the current delay buffer in place. Press again to release (latching).

Grain Env

Smooth
Slow At
Fast At

None
Gran
FM

BYPASS / ALT

Granular
Delay/Synth

Hold

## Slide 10

FunBox is a pedal platform designed around the Daisy Seed. Fits in a 125B enclosure.

- Stereo ¼” In/Out Jacks
- 9v Center Negative Power

FunBox

Two Momentary Footswitches
with indication LEDs.

Expression Input (1/8” TRS Jack)

Expression

Knob 1

Knob 2

Knob 3

MIDI

MIDI Input (1/8” TRS Jack)

6 Potentiometer Knobs

Knob 4

Knob 5

Knob 6

USB

Daisy Seed USB port

Three 3-way Toggles (On-Off-On)

Specs:
- Buffered Stereo In/Out Paths
- Up to 96KHz, 24-bit Digital Processing
- 64MB SDRAM, 8MB Flash
- ARM Cortex M7 480MHz
- Expression and MIDI Inputs
- Through Hole PCB
- Digital Bypass only

Toggle 1

Opt 1
Opt 2
Opt 3

Toggle 2

Opt 1
Opt 2
Opt 3

Toggle 3

Opt 1
Opt 2
Opt 3

4 On/Off Dipswitches

FootSw 1

FootSw 2

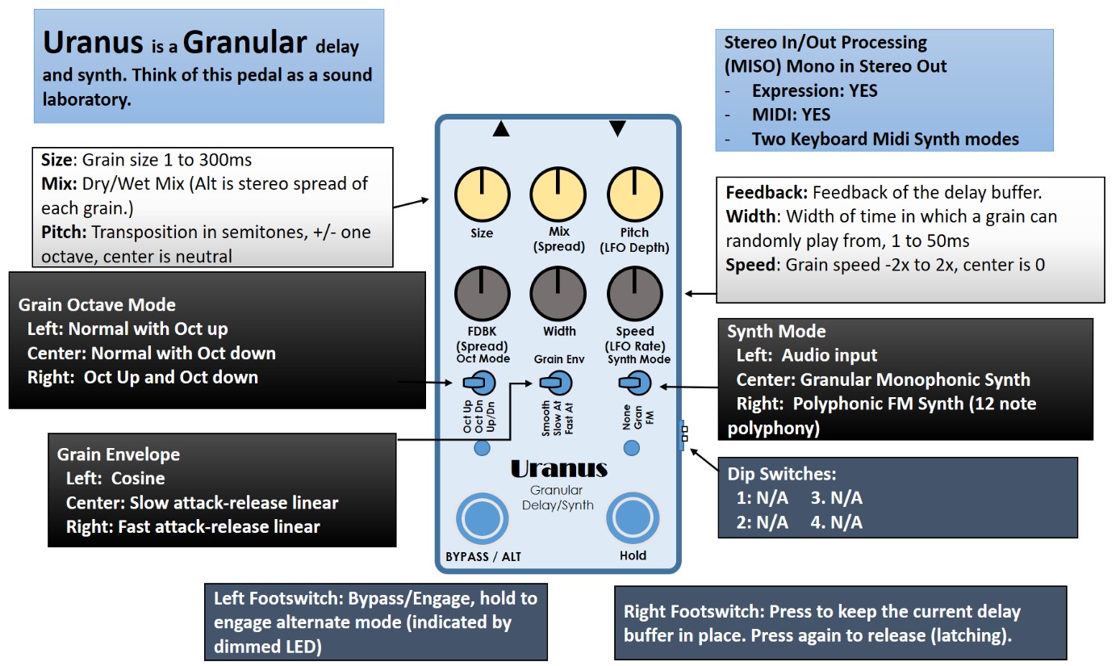
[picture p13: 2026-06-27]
software/images/uranus_infographic.jpg

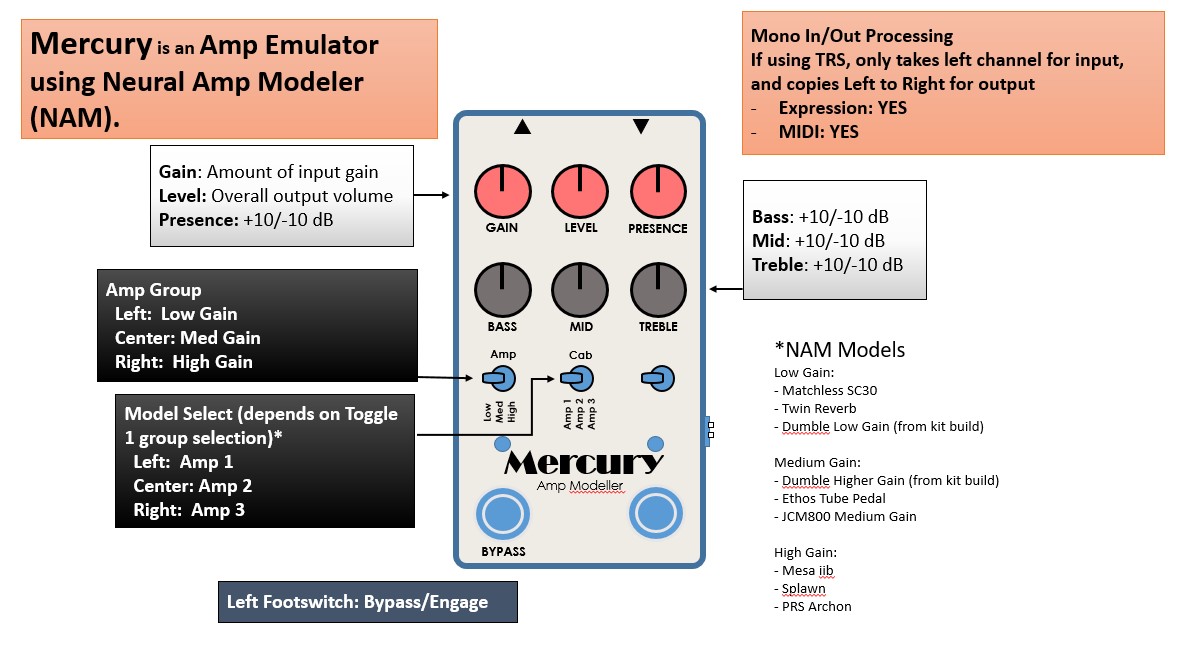
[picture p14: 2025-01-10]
software/images/mercury_infographic.jpg

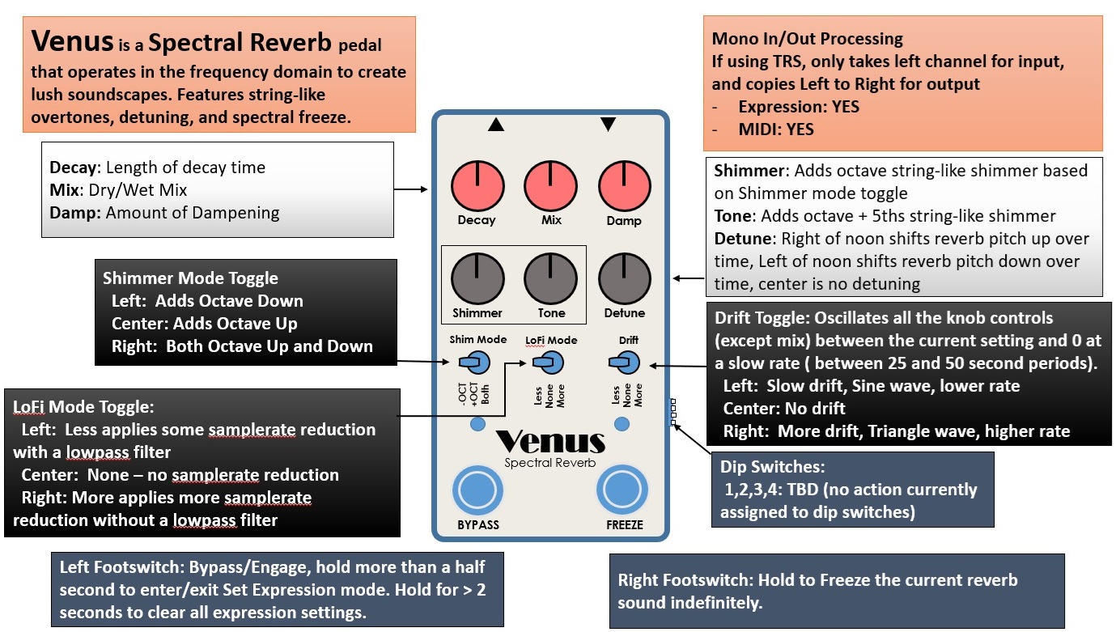
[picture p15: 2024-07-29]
software/images/venus_infographic.jpg

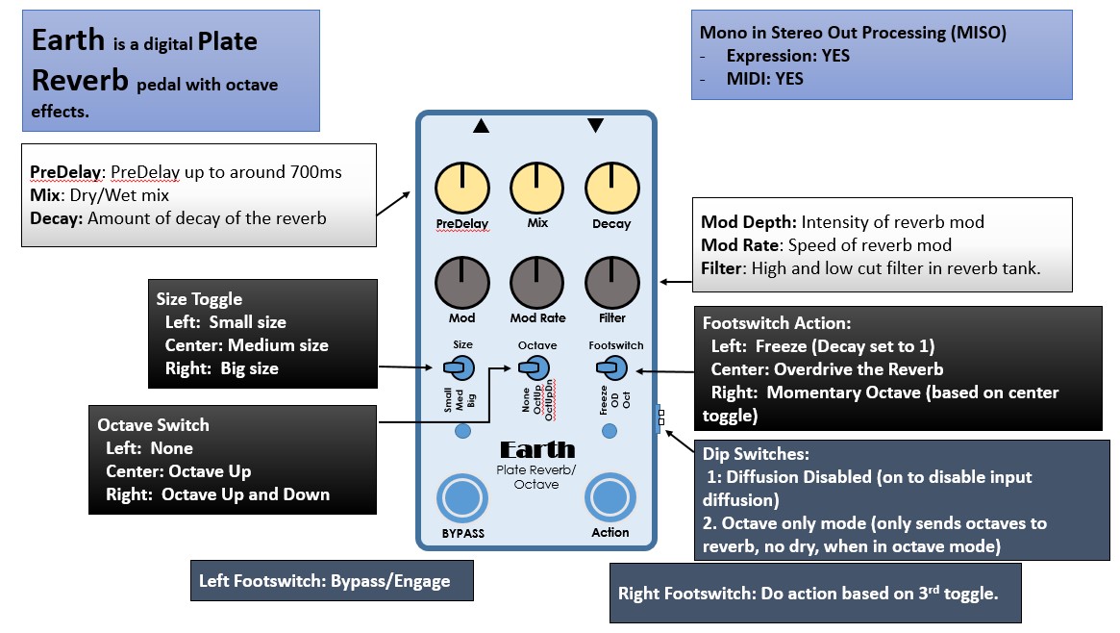
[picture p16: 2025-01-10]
software/images/earth_infographic.jpg

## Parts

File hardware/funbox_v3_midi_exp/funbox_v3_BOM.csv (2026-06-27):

Id | Designator | Footprint | Quantity | Designation | Supplier and ref
1 | R30 | R_Axial_DIN0207_L6.3mm_D2.5mm_P7.62mm_Horizontal | 1 | 220 ohm
2 | POT4,POT5,POT2,POT1,POT3,POT6 | Pot_RightAngle_LongPin_16mm | 6 | 10K | RV16AF-41-15R1-B10K | https://www.taydaelectronics.com/b10k-ohm-linear-taper-potentiometer-round-shaft-pc-mount-l.html
3 | OutR,InG,InL,InR,OutG,OutL,9v,Gnd | TestPoint_THTPad_D2.0mm_Drill1.0mm | 8 | ~
4 | C15,C4,C5,C14,C17,C1 | C_Rect_L7.0mm_W6.0mm_P5.00mm | 6 | 1UF
5 | C13,C12 | C_Rect_L7.0mm_W2.5mm_P5.00mm | 2 | 2.2nF
6 | R31 | R_Axial_DIN0207_L6.3mm_D2.5mm_P7.62mm_Horizontal | 1 | 470 ohm
7 | D2 | D_DO-35_SOD27_P7.62mm_Horizontal | 1 | 1N4148
8 | J7 | PJ-320A | 1 | EXPRESSION | https://www.taydaelectronics.com/pj-320a-3-5-mm-audio-socket-through-hole-pcb-silver-plated.html
9 | R12,R8,R3,R9 | R_Axial_DIN0207_L6.3mm_D2.5mm_P7.62mm_Horizontal | 4 | 1K
10 | U2 | TO-220-3_Vertical | 1 | L78L05ACZ | https://www.taydaelectronics.com/l78l05acz-l78l05-78l05-5-volts-100ma-voltage-regulator-ic.html
11 | SW1,SW2,SW3 | SW_Toggle_SPDT_lugs | 3 | SW_SPDT | 1MS3T2B1M1QES | https://www.taydaelectronics.com/mini-toggle-switch-1m-series-spdt-on-off-on-short-lever.html
12 | R6,R5,R16,R1,R15,R13,R14,R2 | R_Axial_DIN0207_L6.3mm_D2.5mm_P7.62mm_Horizontal | 8 | 1M
13 | C8,C9,C7,C10 | C_Rect_L7.0mm_W2.5mm_P5.00mm | 4 | 100NF
14 | C6 | CP_Radial_D8.0mm_P3.50mm | 1 | 100UF
15 | C11,C2 | C_Rect_L7.0mm_W2.5mm_P5.00mm | 2 | 100pF
16 | LED2 | PinHeader_1x02_P2.54mm_Vertical | 1 | LED_2 (5mm, color as desired) | 732-5017-ND (Digikey)
17 | C30 | C_Disc_D6.0mm_W2.5mm_P5.00mm | 1 | 100NF
18 | R4,R17 | R_Axial_DIN0207_L6.3mm_D2.5mm_P7.62mm_Horizontal | 2 | 100 ohm
19 | LED1 | PinHeader_1x02_P2.54mm_Vertical | 1 | LED_1 (5mm, color as desired) | 732-5017-ND (Digikey)
20 | C16,C3 | C_Rect_L7.0mm_W2.5mm_P5.00mm | 2 | 1NF
21 | R11,R10 | R_Axial_DIN0207_L6.3mm_D2.5mm_P7.62mm_Horizontal | 2 | 3K3
22 | U1 | DIP-14_W7.62mm | 1 | MCP6024-I/P | Digikey MCP6024-I/P-ND
23 | A1 | Electrosmith_Daisy_Seed | 1 | Electrosmith_Daisy_Seed_Rev7 (soldered, 65MB memory version) | https://electro-smith.com/products/daisy-seed?variant=45234245140772
24 | D1 | D_DO-41_SOD81_P7.62mm_Horizontal | 1 | 1N5817
25 | U3 | DIP-8_W7.62mm | 1 | MCP6002-I/P
26 | S1 | DS03-254-04BE-dip4 | 1 | DS03-254-04BE
27 | R18,R7 | R_Axial_DIN0207_L6.3mm_D2.5mm_P7.62mm_Horizontal | 2 | 100K
28 | FS1 | PinHeader_1x02_P2.54mm_Vertical | 1 | Foot_Switch_1 | https://lovemyswitches.com/pro-grade-spst-momentary-foot-switch-normally-open-soft-touch-solder-lug/
29 | J6 | PJ-320A | 1 | MIDI IN | https://www.taydaelectronics.com/pj-320a-3-5-mm-audio-socket-through-hole-pcb-silver-plated.html
30 | FS2 | PinHeader_1x02_P2.54mm_Vertical | 1 | Foot_Switch_2 | https://lovemyswitches.com/pro-grade-spst-momentary-foot-switch-normally-open-soft-touch-solder-lug/
31 | U5 | DIP-6_W7.62mm | 1 | H11L1M | https://www.taydaelectronics.com/h11l1-h11l1m-high-speed-optocouplers-output-1-channel.html
32 | R19 | R_Axial_DIN0207_L6.3mm_D2.5mm_P7.62mm_Horizontal | 1 | 2M

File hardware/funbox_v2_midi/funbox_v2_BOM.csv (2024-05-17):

Source: | /Users/keithbloemer/Desktop/KiCad/FunBox_v2_midi/funbox_v2.kicad_sch
Date: | 2024 May 17, Friday 12:03:38
Tool: | Eeschema 7.0.6-0
Generator: | /Applications/KiCad/KiCad.app/Contents/SharedSupport/plugins/bom_csv_grouped_by_value.py
Component Count: | 70
Collated Components:
Item | Qty | Reference(s) | Value | LibPart | Footprint | Datasheet | DNP | MANUFACTURER | MAXIMUM_PACKAGE_HEIGHT | PARTREV | STANDARD | Sim.Device | Sim.Pins
1 | 1 | A1 | Electrosmith_Daisy_Seed_Rev7 | MCU_Module:Electrosmith_Daisy_Seed_Rev4 | Module:Electrosmith_Daisy_Seed | https://static1.squarespace.com/static/58d03fdc1b10e3bf442567b8/t/6227e6236f02fb68d1577146/1646781988478/Daisy_Seed_datasheet_v1.0.3.pdf
2 | 2 | C1, C2 | 100 | Device:C | Capacitor_THT:C_Rect_L7.0mm_W2.5mm_P5.00mm | ~
3 | 2 | C3, C4 | 2.2nF | Device:C | Capacitor_THT:C_Rect_L7.0mm_W2.5mm_P5.00mm | ~
4 | 6 | C5, C11, C12, C13, C16, C17 | 1UF | Device:C | Capacitor_THT:C_Rect_L7.0mm_W6.0mm_P5.00mm | ~
5 | 1 | C6 | 100UF | Device:C | Capacitor_THT:CP_Radial_D8.0mm_P3.50mm | ~
6 | 4 | C7, C8, C9, C10 | 100NF | Device:C | Capacitor_THT:C_Rect_L7.0mm_W2.5mm_P5.00mm | ~
7 | 2 | C14, C15 | 1NF | Device:C | Capacitor_THT:C_Rect_L7.0mm_W2.5mm_P5.00mm | ~
8 | 1 | C30 | 100NF | Device:C | Capacitor_THT:C_Disc_D6.0mm_W2.5mm_P5.00mm | ~
9 | 1 | D1 | 1N5817 | Diode:1N5817 | Diode_THT:D_DO-41_SOD81_P7.62mm_Horizontal | http://www.vishay.com/docs/88525/1n5817.pdf
10 | 1 | D2 | 1N4148 | Diode:1N4148 | Diode_THT:D_DO-35_SOD27_P7.62mm_Horizontal | https://assets.nexperia.com/documents/data-sheet/1N4148_1N4448.pdf |  |  |  |  |  | D | 1=K 2=A
11 | 1 | FS1 | Foot_Switch_1 | Switch:SW_Push | Connector_PinHeader_2.54mm:PinHeader_1x02_P2.54mm_Vertical | ~
12 | 1 | FS2 | Foot_Switch_2 | Switch:SW_Push | Connector_PinHeader_2.54mm:PinHeader_1x02_P2.54mm_Vertical | ~
13 | 8 | In1, In2, In3, InG1, InG2, InG3, Out1, Out2 | ~ | Connector_Generic:Conn_01x01 | TestPoint:TestPoint_THTPad_D2.0mm_Drill1.0mm | ~
14 | 1 | J6 | MIDI IN JACK | Connector_Audio:AudioJack4 | Audio_Module:TRRS-PJ-320A | ~
15 | 1 | J7 | MIDI OUT JACK | Connector_Audio:AudioJack4 | Audio_Module:TRRS-PJ-320A | ~
16 | 1 | LED1 | LED_1 | Device:LED | Connector_PinHeader_2.54mm:PinHeader_1x02_P2.54mm_Vertical | ~
17 | 1 | LED2 | LED_2 | Device:LED | Connector_PinHeader_2.54mm:PinHeader_1x02_P2.54mm_Vertical | ~
18 | 6 | POT1, POT2, POT3, POT4, POT5, POT6 | 10K | Device:R_Potentiometer_US | Potentiometer_THT:Pot_RightAngle_LongPin_16mm | ~
19 | 2 | R1, R2 | 3K3 | Device:R | Resistor_THT:R_Axial_DIN0207_L6.3mm_D2.5mm_P7.62mm_Horizontal | ~
20 | 4 | R3, R4, R8, R9 | 1K | Device:R | Resistor_THT:R_Axial_DIN0207_L6.3mm_D2.5mm_P7.62mm_Horizontal | ~
21 | 8 | R5, R6, R7, R10, R11, R12, R13, R14 | 1M | Device:R | Resistor_THT:R_Axial_DIN0207_L6.3mm_D2.5mm_P7.62mm_Horizontal | ~
22 | 2 | R15, R16 | 100 | Device:R | Resistor_THT:R_Axial_DIN0207_L6.3mm_D2.5mm_P7.62mm_Horizontal | ~
23 | 2 | R17, R18 | 100K | Device:R | Resistor_THT:R_Axial_DIN0207_L6.3mm_D2.5mm_P7.62mm_Horizontal | ~
24 | 1 | R30 | 220R | Device:R | Resistor_THT:R_Axial_DIN0207_L6.3mm_D2.5mm_P7.62mm_Horizontal | ~
25 | 1 | R31 | 470R | Device:R | Resistor_THT:R_Axial_DIN0207_L6.3mm_D2.5mm_P7.62mm_Horizontal | ~
26 | 1 | R32 | 10R | Device:R | Resistor_THT:R_Axial_DIN0207_L6.3mm_D2.5mm_P7.62mm_Horizontal | ~
27 | 1 | R33 | 33R | Device:R | Resistor_THT:R_Axial_DIN0207_L6.3mm_D2.5mm_P7.62mm_Horizontal | ~
28 | 1 | S1 | DS03-254-04BE | DS03-254-04BE:DS03-254-04BE | Button_Switch_THT:DS03-254-04BE-dip4 |  |  | CUI Inc. | 9.93 mm | V1.0 | Manufacturer Recommendations
29 | 3 | SW1, SW2, SW3 | SW_SPDT | Switch:SW_SPDT | Button_Switch_THT:SW_Toggle_SPDT_lugs | ~
30 | 1 | U1 | TL074 | Amplifier_Operational:TL074 | Package_DIP:DIP-14_W7.62mm | http://www.ti.com/lit/ds/symlink/tl071.pdf
31 | 1 | U2 | L7805 | Regulator_Linear:L7805 | Package_TO_SOT_THT:TO-220-3_Vertical | http://www.st.com/content/ccc/resource/technical/document/datasheet/41/4f/b3/b0/12/d4/47/88/CD00000444.pdf/files/CD00000444.pdf/jcr:content/translations/en.CD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
32 | 1 | U5 | H11L1 | Isolator:H11L1 | Package_DIP:DIP-6_W7.62mm | https://www.onsemi.com/pub/Collateral/H11L3M-D.PDF

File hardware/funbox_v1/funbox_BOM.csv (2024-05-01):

Source: | /Users/keithbloemer/Desktop/KiCad/FunBox/funbox.kicad_sch
Date: | 2024 May 01, Wednesday 12:14:24
Tool: | Eeschema 7.0.6-0
Generator: | /Applications/KiCad/KiCad.app/Contents/SharedSupport/plugins/bom_csv_grouped_by_value.py
Component Count: | 61
Collated Components:
Item | Qty | Reference(s) | Value | LibPart | Footprint | Datasheet | DNP | MANUFACTURER | MAXIMUM_PACKAGE_HEIGHT | PARTREV | STANDARD
1 | 8 | 9v1, Gnd1, In1, In2, InG1, Out1, Out2, OutG1 | ~ | Connector_Generic:Conn_01x01 | TestPoint:TestPoint_THTPad_D2.0mm_Drill1.0mm | ~
2 | 1 | A1 | Electrosmith_Daisy_Seed_Rev7 | MCU_Module:Electrosmith_Daisy_Seed_Rev4 | Module:Electrosmith_Daisy_Seed | https://static1.squarespace.com/static/58d03fdc1b10e3bf442567b8/t/6227e6236f02fb68d1577146/1646781988478/Daisy_Seed_datasheet_v1.0.3.pdf
3 | 6 | C1, C4, C5, C14, C15, C17 | 1UF | Device:C | Capacitor_THT:C_Rect_L7.0mm_W6.0mm_P5.00mm | ~
4 | 2 | C2, C11 | 100 | Device:C | Capacitor_THT:C_Rect_L7.0mm_W2.5mm_P5.00mm | ~
5 | 2 | C3, C16 | 1NF | Device:C | Capacitor_THT:C_Rect_L7.0mm_W2.5mm_P5.00mm | ~
6 | 1 | C6 | 100UF | Device:C | Capacitor_THT:CP_Radial_D8.0mm_P3.50mm | ~
7 | 4 | C7, C8, C9, C10 | 100NF | Device:C | Capacitor_THT:C_Rect_L7.0mm_W2.5mm_P5.00mm | ~
8 | 2 | C12, C13 | 2.2nF | Device:C | Capacitor_THT:C_Rect_L7.0mm_W2.5mm_P5.00mm | ~
9 | 1 | D1 | 1N5817 | Diode:1N5817 | Diode_THT:D_DO-41_SOD81_P7.62mm_Horizontal | http://www.vishay.com/docs/88525/1n5817.pdf
10 | 1 | FS1 | Foot_Switch_1 | Switch:SW_Push | Connector_PinHeader_2.54mm:PinHeader_1x02_P2.54mm_Vertical | ~
11 | 1 | FS2 | Foot_Switch_2 | Switch:SW_Push | Connector_PinHeader_2.54mm:PinHeader_1x02_P2.54mm_Vertical | ~
12 | 1 | LED1 | LED_1 | Device:LED | Connector_PinHeader_2.54mm:PinHeader_1x02_P2.54mm_Vertical | ~
13 | 1 | LED2 | LED_2 | Device:LED | Connector_PinHeader_2.54mm:PinHeader_1x02_P2.54mm_Vertical | ~
14 | 6 | POT1, POT2, POT3, POT4, POT5, POT6 | 10K | Device:R_Potentiometer_US | Potentiometer_THT:Pot_RightAngle_LongPin_16mm | ~
15 | 8 | R1, R2, R5, R6, R13, R14, R15, R16 | 1M | Device:R | Resistor_THT:R_Axial_DIN0207_L6.3mm_D2.5mm_P7.62mm_Horizontal | ~
16 | 4 | R3, R8, R9, R12 | 1K | Device:R | Resistor_THT:R_Axial_DIN0207_L6.3mm_D2.5mm_P7.62mm_Horizontal | ~
17 | 2 | R4, R17 | 100 | Device:R | Resistor_THT:R_Axial_DIN0207_L6.3mm_D2.5mm_P7.62mm_Horizontal | ~
18 | 2 | R7, R18 | 100K | Device:R | Resistor_THT:R_Axial_DIN0207_L6.3mm_D2.5mm_P7.62mm_Horizontal | ~
19 | 2 | R10, R11 | 3K3 | Device:R | Resistor_THT:R_Axial_DIN0207_L6.3mm_D2.5mm_P7.62mm_Horizontal | ~
20 | 1 | S1 | DS03-254-02BE | DS03-254-02BE:DS03-254-02BE | Button_Switch_THT:DS03-254-02BE-dip2 |  |  | CUI Inc. | 9.93 mm | V1.0 | Manufacturer Recommendations
21 | 3 | SW1, SW2, SW3 | SW_SPDT | Switch:SW_SPDT | Button_Switch_THT:SW_Toggle_SPDT_lugs | ~
22 | 1 | U1 | TL074 | Amplifier_Operational:TL074 | Package_DIP:DIP-14_W7.62mm | http://www.ti.com/lit/ds/symlink/tl071.pdf
23 | 1 | U2 | L7805 | Regulator_Linear:L7805 | Package_TO_SOT_THT:TO-220-3_Vertical | http://www.st.com/content/ccc/resource/technical/document/datasheet/41/4f/b3/b0/12/d4/47/88/CD00000444.pdf/files/CD00000444.pdf/jcr:content/translations/en.CD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

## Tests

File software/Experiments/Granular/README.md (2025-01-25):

# Granular

Experiment testing out the GranularPlayer class in DaisySP. Uses a triggered 2 second sample recorder.

## Controls

| Control | Description | Comment |
| --- | --- | --- |
| Ctrl 1 | Size | Grain size 1ms to 200ms |
| Ctrl 2 | Speed | Speed of grain playback -2x to +2x |
| Ctrl 3 | Pitch | Pitch (transposition) of the grains, -1 to +1 octave |
| Ctrl 4 | Mix | Controls the Attack/Decay time of both the modulator and carrier |
| Ctrl 5 | Level | Controls the sustain level (volume while note is held) |
| Ctrl 6 |  |  |
| 3-Way Switch 1 |  | |
| 3-Way Switch 2 |  |  |
| 3-Way Switch 3 |  |  |
| Dip Switch 1 |  |  |
| Dip Switch 2 |  |  |
| FS 1 | Bypass |  |
| FS 2 | Trigger | Trigger recording a sample (will repeat until another sample is recorded) |
| LED 1 | Bypass Indicator |  |
| LED 2 | Recording Indicator | |
| Audio In 1 | N/A | Ignores Right channel input  |
| Audio Out 1 | Stereo | |

Expression controls Knob 2 only, Speed. Plug in expression pedal to use, move knob 2 to deactivate expression control.

## Build

Granular runs in Flash memory on the Daisy Seed.

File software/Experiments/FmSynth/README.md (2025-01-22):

# FmSynth

Experiment creating a FM Synth for Midi keyboard using Funbox. This synth uses just two operators, a modulator and a carrier. The modulator oscillator
uses phase modulation to change the timbre of the carrier oscillator. An ADSR envelope is applied to both the modulator and carrier. 
The controls have been simplified to fit within the 6 knobs on Funbox.

## Controls

| Control | Description | Comment |
| --- | --- | --- |
| Ctrl 1 | Level | The carrier level, or overall output of the synth |
| Ctrl 2 | Mod level | The modulator level, which changes the timbre of the sound |
| Ctrl 3 | Mod Ratio | Frequency multiplier of the modulator, from 0.5 to 16 by increments of 0.5, multiplied by the base frequncy of the note |
| Ctrl 4 | Attack | Controls the Attack/Decay time of both the modulator and carrier |
| Ctrl 5 | Sustain | Controls the sustain level (volume while note is held) |
| Ctrl 6 | Release | Controls the release time of the note |
| 3-Way Switch 1 |  | |
| 3-Way Switch 2 |  |  |
| 3-Way Switch 3 |  |  |
| Dip Switch 1 |  |  |
| Dip Switch 2 |  |  |
| FS 1 | Bypass |  |
| FS 2 |  |  |
| LED 1 | Bypass Indicator |  |
| LED 2 | Lights up for MIDI Notes Received | |
| Audio In 1 | N/A | Ignores Right channel input  |
| Audio Out 1 | Stereo | |

Expression controls Knob 2 only, Mod Level. Plug in expression pedal to use, move knob 2 to deactivate expression control.

### MIDI Reference

| Control | MIDI CC | Value |
| --- | --- | --- |
| Knob 1 | 14 | 0- 127 |
| Knob 2 | 15 | 0- 127 |
| Knob 3 | 16 | 0- 127 |
| Knob 4 | 17 | 0- 127 |
| Knob 5 | 18 | 0- 127 |
| Knob 6 | 19 | 0- 127 |

Takes Keyboard Midi input to play a sound.

## Build

MidiKeys runs in Flash memory on the Daisy Seed.

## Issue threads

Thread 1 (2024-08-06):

BOM - capacitors

VisionOneSrl, 2024-08-06:
I'm trying to build a funbox and I've a problem with the bom

https://github.com/GuitarML/FunBox/blob/main/hardware/funbox_v3_midi_exp/funbox_v3_BOM.csv

the item 2, C1 and C2 capacitors has a value of 100 but is not specified unit of measure in Farad.
Also how can I know if a capacitor is electrolitic, polyester o ceramic?

GuitarML, 2024-08-19:
It's 100pF, I will update the BOM with units and type, thanks!

Closed 2024-10-30.

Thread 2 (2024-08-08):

BOM - Resistors

VisionOneSrl, 2024-08-08:
Item 22: R15, R16 the value is 100 Ohm?

Items 25, 26: what is the R appended? It means just Ohms?

GuitarML, 2024-08-19:
Yes, 100 ohms, and the R just designates ohms. I'll update the bom to be more clear, thanks!

Closed 2024-10-30.

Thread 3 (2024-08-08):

Add a simple display & encoder to v4 revision

sejerpz, 2024-08-08:
What's your opinion about adding a simple display and an encoder to the hardware?

GuitarML, 2024-08-19:
I probably won't be adding a screen, I had a specific layout in mind when designing the Funbox. There is another great project that has a screen/encoder that I've used, so a screen in this project seems redundant to me, here is the other project:

https://github.com/bkshepherd/DaisySeedProjects

If someone did want to add a screen to FunBox, they'd probably need to either use a bigger enclosure, or design a board with smd components instead of through-hole.

sejerpz, 2024-08-20:
Thanks for the link, but soldering smd is too much for me :)

Funbox is such a great a simple design but I'd like to have more options to display info to the user beside just the two leds.

dccourt, 2025-05-29:
I found that it's easy to mount a similar screen to the bkshepherd one onto the outside of the FunBox case, just in front of the footswitches.  FunBox doesn't use the I2C1 pins, so I've been able to add successfully add the I2C screen variant to the bkshepherd code and have it running.  I don't think there's room for an encoder, but I don't think it's really needed, and I have in mind a software mod to use a knob when the footswitch is pressed, or similar, if I find that I do miss it.

I feel that a screen would add similar utility to FunBox as it does to the bkshepherd project - i.e. providing feedback when the controls are adjusted, which allows for the pedal to be self-documenting.

dccourt, 2025-08-31:
@da6353 Sure, see https://github.com/dccourt/FunBox/releases/tag/screen_v1 .

@GuitarML Sure, will take a while before I'm able to draft up a PCB.

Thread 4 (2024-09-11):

Funbox vers. 3.2 - Software pin mapping is wrong.

sejerpz, 2024-09-11:
After building the Funbox I tried some of your effects and I notice that some controls don't work at all.

So I tried the Template project and I notice the same.

Debugging the problem I see that some pin mapping are wrong in software, I see that daisy petal is used as a base.

The wrong mappings I found are: Footswitches 1 & 2, all the 3 switches
I didn't test the dip switch yet.

This is my working code:

`fs1.Init(seed::D25);`
`fs2.Init(seed::D26);`

`sw1a.Init(seed::D14);`
`sw1b.Init(seed::D13);`

`sw2a.Init(seed::D7);`
`sw2b.Init(seed::D10);`

`sw3a.Init(seed::D2);`
`sw3b.Init(seed::D4);`

I've also a question: why use the DaisyPetal as a foundation class? Why not creating a Funbox[v32] class with just the hardware and connections present?

GuitarML, 2024-09-16:
@sejerpz did you replace the daisy_petal .h and .cpp files in libdaisy with the ones in my Funbox/mod folder prior to building libdaisy? You’ll need to do that to get the correct switch mappings, I think the only ones I kept the same as the original daisy petal are the knobs.

sejerpz, 2024-09-23:
Oh, no, I didn't do that, how could I miss that clear notice. Sorry.

Anyway I wrote a funbox.h with all the code and used that instead.

If you are interested I can make a PR.

Closed 2024-09-23.

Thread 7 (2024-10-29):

Missing Footprints

CarFlip, 2024-10-29:
Hello.
I was updating the PCB from the schematic in KiCad, and it seems there are some missing footprints in the design. I’m not sure if these footprints were custom-made or from a library I haven’t downloaded. Could you let me know if they’re available in a specific library, or if there’s a recommended way to recreate or replace them?

Thanks for your help, and great work on the project

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

CarFlip, 2024-10-30:
Also i seems the schematics are still using the TL074 instead of the MCP6024

GuitarML, 2024-10-30:
@CarFlip Yes, I left out those footprint files because I believe where I got them were under a slightly different kind of license, so as a precaution I left them out of my repo. And yes I'll need to rename the quad op amp in the schematic. Thanks!

Closed 2024-11-17.

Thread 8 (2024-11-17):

Audio In Voltage

CarFlip, 2024-11-17:
Hello, i have made a pcb using the schematic you provided for Funbox V3. When 9V power is applied to it, the voltage at the audio inputs is 2.49V. I feel this is too high and may damage the daisy as the daisy datasheet says 1.8V maximum for those pins. I am using the TL074 Op amp. Is that the correct voltage for those pins or have i done something wrong.

Thanks.

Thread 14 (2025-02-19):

Q about part#

jpnielsen, 2025-02-19:
I found some 1uF polypropylene caps, 1uF 100V on aliexpress that fits under the daisy using a medium height IC socket (8.5mm).
Digikey have a couple of caps that fit the description - but they're kind of expensive.
I'm curious, what capacitors do you use ?

https://github.com/GuitarML/FunBox/blob/54ab5ff19e2c28de45ed135745f5f38aa4512370/hardware/funbox_v3_midi_exp/funbox_v3_BOM.csv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

GuitarML, 2025-02-20:
The ones I got from Tayda were more expensive, I think they were these WIMA types:

https://www.taydaelectronics.com/wima-mks2-1uf-63v-5-polyester-film-box-type-capacitor.html

They're 10mm tall but the daisy seed headers add some space as well.

Closed 2025-02-21.

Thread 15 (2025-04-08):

schematic for v3 schematic not same as pcb

spamatica, 2025-04-08:
Hey there,

Poking around the hardware design (and building the board!) I noticed that something is off between the schematic and the pcb.

I see now in the repo that the pcb file has a commit for v3.2 with the move to MCP6024. I can't see a corresponding commit for the schematic and it still says TL074.
Now, that change isn't so important but the component numbering seems to have changed, which causes a bit more head scratching what I'm looking at.
I can only assume there is a more recent schematic, so if you still have it, please add it to the repo :)

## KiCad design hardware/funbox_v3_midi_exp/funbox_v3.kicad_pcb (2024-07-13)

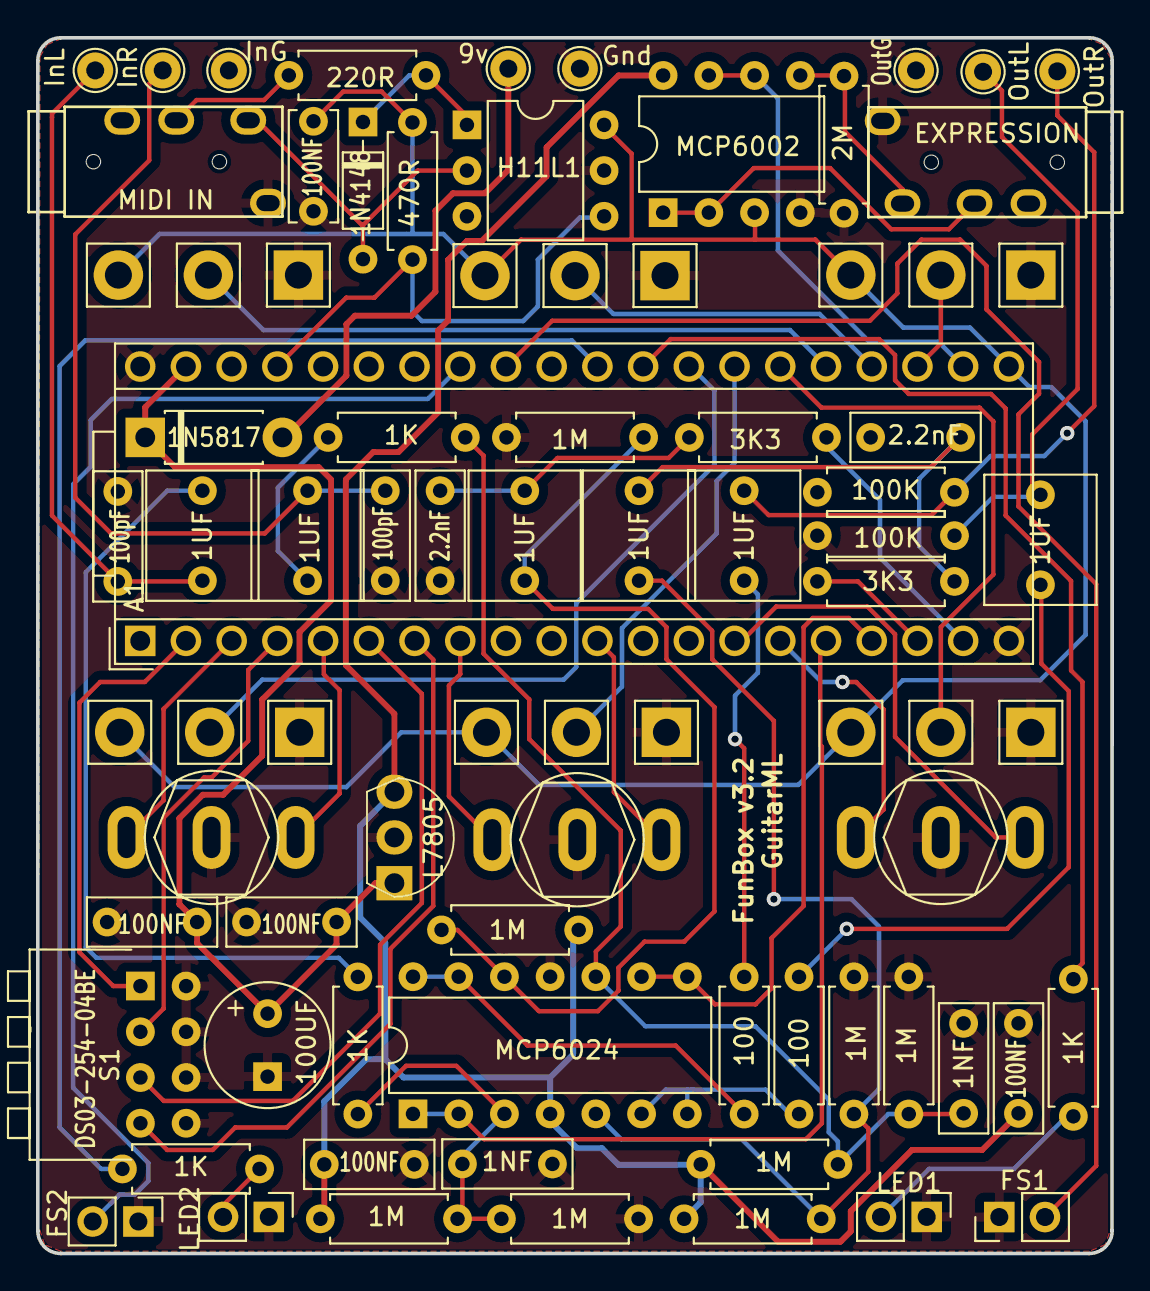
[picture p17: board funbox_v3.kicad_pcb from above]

Board: 2 copper layers, 59.7 x 67.5 mm, 70 parts (0 on the bottom side), 54 nets.

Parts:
9v: TestPoint_THTPad_D2.0mm_Drill1.0mm
A1: Electrosmith_Daisy_Seed_Rev7; Electrosmith_Daisy_Seed
C1, C4, C5, C14, C15, C17: 1UF; C_Rect_L7.0mm_W6.0mm_P5.00mm
C2, C11: 100pF; C_Rect_L7.0mm_W2.5mm_P5.00mm
C3, C16: 1NF; C_Rect_L7.0mm_W2.5mm_P5.00mm
C6: 100UF; CP_Radial_D8.0mm_P3.50mm
C7, C8, C9, C10: 100NF; C_Rect_L7.0mm_W2.5mm_P5.00mm
C12, C13: 2.2nF; C_Rect_L7.0mm_W2.5mm_P5.00mm
C30: 100NF; C_Disc_D6.0mm_W2.5mm_P5.00mm
D1: 1N5817; D_DO-41_SOD81_P7.62mm_Horizontal
D2: 1N4148; D_DO-35_SOD27_P7.62mm_Horizontal
FS1: Foot_Switch_1; PinHeader_1x02_P2.54mm_Vertical
FS2: Foot_Switch_2; PinHeader_1x02_P2.54mm_Vertical
Gnd: TestPoint_THTPad_D2.0mm_Drill1.0mm
InG: TestPoint_THTPad_D2.0mm_Drill1.0mm
InL: TestPoint_THTPad_D2.0mm_Drill1.0mm
InR: TestPoint_THTPad_D2.0mm_Drill1.0mm
J6: MIDI IN; TRRS-PJ-320A
J7: EXPRESSION; TRRS-PJ-320A
LED1: LED_1; PinHeader_1x02_P2.54mm_Vertical
LED2: LED_2; PinHeader_1x02_P2.54mm_Vertical
OutG: TestPoint_THTPad_D2.0mm_Drill1.0mm
OutL: TestPoint_THTPad_D2.0mm_Drill1.0mm
OutR: TestPoint_THTPad_D2.0mm_Drill1.0mm
POT1, POT2, POT3, POT4, POT5, POT6: 10K; Pot_RightAngle_LongPin_16mm
R1, R2, R5, R6, R13, R14, R15, R16: 1M; R_Axial_DIN0207_L6.3mm_D2.5mm_P7.62mm_Horizontal
R3, R8, R9, R12: 1K; R_Axial_DIN0207_L6.3mm_D2.5mm_P7.62mm_Horizontal
R4, R17: 100; R_Axial_DIN0207_L6.3mm_D2.5mm_P7.62mm_Horizontal
R7, R18: 100K; R_Axial_DIN0207_L6.3mm_D2.5mm_P7.62mm_Horizontal
R10, R11: 3K3; R_Axial_DIN0207_L6.3mm_D2.5mm_P7.62mm_Horizontal
R19: 2M; R_Axial_DIN0207_L6.3mm_D2.5mm_P7.62mm_Horizontal
R30: 220R; R_Axial_DIN0207_L6.3mm_D2.5mm_P7.62mm_Horizontal
R31: 470R; R_Axial_DIN0207_L6.3mm_D2.5mm_P7.62mm_Horizontal
S1: DS03-254-04BE; DS03-254-04BE-dip4
SW1, SW2, SW3: SW_SPDT; SW_Toggle_SPDT_lugs
U1: MCP6024; DIP-14_W7.62mm
U2: L7805; TO-220-3_Vertical
U3: MCP6002; DIP-8_W7.62mm
U5: H11L1; DIP-6_W7.62mm

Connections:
3V3_A: A1.21 (3V3_A), C30.1, POT1.3, POT2.3, POT3.3, POT4.3, POT5.3, POT6.3, R31.1, U3.3 (+), U5.6
5V: C9.2, C10.2, R2.1, R5.1, R13.1, R15.1, U1.4 (V+), U2.3 (OUT), U3.8 (V+)
AUDIO_IN_BUFFER_LEFT: A1.16 (AUDIO_IN_1), U1.1, U1.2 (-)
AUDIO_IN_BUFFER_RIGHT: A1.17 (AUDIO_IN_2), U1.8, U1.9 (-)
AUDIO_OUT_BUFFER_LEFT: A1.18 (AUDIO_OUT_1), R11.1
AUDIO_OUT_BUFFER_RIGHT: A1.19 (AUDIO_OUT_2), R10.1
DIP1: A1.2 (SD_DATA_3), S1.1A
DIP2: A1.4 (SD_DATA_1), S1.2A
DIP3: A1.6 (SD_CMD), S1.3A
DIP4: A1.7 (SD_CLK), S1.4A
EXPRESSION_IN: A1.22 (ADC_0), U3.6 (-), U3.7
EXPRESSION_IN_JACK: J7.T, R19.1, U3.5 (+)
EXPRESSION_REF: J7.R1, U3.1, U3.2 (-)
FOOT_SWITCH_1: A1.32 (SAI2_SD_B), FS1.2
FOOT_SWITCH_2: A1.33 (SAI2_SD_A), FS2.2
GND: A1.20 (AGND), A1.40 (DGND), C2.2, C3.1, C6.1, C7.1, C8.1, C9.1, C10.1, C11.2, C12.2, C13.2, C16.1, C30.2, FS1.1, FS2.1, Gnd.1, InG.1, J6.S, J7.S, LED1.1 (K), LED2.1 (K), OutG.1, POT1.1, POT2.1, POT3.1, POT4.1, POT5.1, POT6.1, R1.2, R6.2, R7.1, R14.2, R16.2, R18.1, R19.2, S1.1B, S1.2B, S1.3B, S1.4B, SW1.2 (B), SW2.2 (B), SW3.2 (B), U1.11 (V-), U2.2 (GND), U3.4 (V-), U5.5
LED_1: A1.29 (DAC_OUT2), R8.2
LED_2: A1.30 (DAC_OUT1), R9.2
MIDI_IN: A1.37 (USB_D_+), R31.2, U5.4
MIDI_IN_JACK_PIN4: J6.R1, R30.1
MIDI_IN_JACK_PIN5: D2.2 (A), J6.T, U5.2
unnamed: 9v.1, D1.2 (A)
unnamed: C1.2, R3.1
unnamed: C5.2, R4.2
unnamed: C4.1, C12.1, R11.2
unnamed: C13.1, C15.1, R10.2
unnamed: C14.2, R12.1
unnamed: C17.2, R17.2
unnamed: D2.1 (K), R30.2, U5.1
unnamed: C1.1, C2.1, InL.1
unnamed: C11.1, C14.1, InR.1
unnamed: LED1.2 (A), R8.1
unnamed: LED2.2 (A), R9.1
unnamed: C5.1, OutL.1, R7.2
unnamed: C17.1, OutR.1, R18.2
unnamed: C3.2, R1.1, R2.2, R3.2, U1.3 (+)
unnamed: C4.2, R5.2, R6.1, U1.5 (+)
unnamed: R4.1, U1.6 (-), U1.7
unnamed: C16.2, R12.2, R15.2, R16.1, U1.10 (+)
unnamed: C15.2, R13.2, R14.1, U1.12 (+)
unnamed: R17.1, U1.13 (-), U1.14
POT_1: A1.23 (ADC_1), POT1.2
POT_2: A1.24 (ADC_2), POT2.2
POT_3: A1.25 (ADC_3), POT3.2
POT_4: A1.26 (ADC_4), POT4.2
POT_5: A1.27 (ADC_5), POT5.2
POT_6: A1.28 (ADC_6), POT6.2
SW1_LEFT: A1.15 (USART1_RX), SW1.3 (C)
SW1_RIGHT: A1.14 (USART1_TX), SW1.1 (A)
SW2_LEFT: A1.8 (SPI1_CS), SW2.3 (C)
SW2_RIGHT: A1.11 (SPI1_PICO), SW2.1 (A)
SW3_LEFT: A1.3 (SD_DATA_2), SW3.3 (C)
SW3_RIGHT: A1.5 (SD_DATA_0), SW3.1 (A)
VCC: A1.39 (VIN), C6.2, C7.2, C8.2, D1.1 (K), U2.1 (IN)

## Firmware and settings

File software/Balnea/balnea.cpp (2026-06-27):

// Balnea Digital Delay / Pitch Shifter Pedal

#include "daisy_petal.h"
#include "daisysp.h"
#include "funbox.h"
//#include "expressionHandler.h" // Not using normal funbox expression handler for Balnea

#include "tape_modulator.h"
#include "vox.h"
#include "delayline_reverse.h"


using namespace daisy;
using namespace daisysp;
using namespace funbox; 

#define SAMPLING_FREQUENCY_HZ 48000

// Declare a local daisy_petal for hardware access
DaisyPetal hw;
::daisy::Parameter mix, Lpf, regen, glide, int1, int2, expression;
bool      bypass;
Led led1, led2;

float delayModRate, delayModDepth, wetMix, dryMix, glide_float, delayFeedback;

// Alternate functions

bool update_switches;

bool force_reset;

bool mode_changed;
bool triggerMode;

bool            pswitch1[2], pswitch2[2], pswitch3[2], pdip[4];
int             switch1[2], switch2[2], switch3[2], dip[4];

// Initialize "previous" p values
float psize, pmodify, pdelayTime, pmix;
float pLpf, pint1, pint2, pexpression;

// Expression
bool expression_pressed = false;
bool expressionControl = false;

// Midi
bool midi_control[6]; //  just knobs for now
float pknobValues[6]; // Used for Midi control logic

float knobValues[6];
int toggleValues[3];
bool dipValues[4];


// Params
float delayBaseSpeed;
float delaySpeedMultiplier_int1;
float delaySpeedMultiplier_int2;

int leftTogglePosition2 = 0;
int leftTogglePosition = 0;
int rightTogglePosition = 0;



//Bypass / Alternate mode footswitch

bool alternateMode = false;

// Tap Tempo
uint32_t tap_debounce_threshold = 100;  // is this about 50ms?
uint32_t tap_debounce_wait_timer = 100;
uint8_t tap_debounce_reset = 0;

int tap_sample_timer = 0;
int tap_delay_max_limit = 48000 * 4.0;  // 4 second max delay for now
bool tap_timer_on = false;

int delay_timer = 0;
int current_base_delay_in_samples = 24000; // start with half second delay
bool tap_LED_on = false;

// Sequencer
int sequence_stage = 0; // 0, 1 or 2
int sequence_lengths_in_samples[3] = {24000, 24000, 24000};
int sequence_timer = 0;
float int1_stage_multiplier = 1.0;
float int2_stage_multiplier = 1.0;
float base_stage_multiplier = 1.0;

// Tap Sequencer Mode
bool tapSequencerMode = false;
bool incrementNextSequence = false;

// Reverse Mode
int reverse_mode_timer = 500;
int reverse_mode_timer_threshold = 500;
//bool rStart = true; // Workaround for reverse starting as default, not sure why when everything sets reverse to false at startup

// Self Oscillate mode
int self_osc_hold_timer = 300;
int self_osc_hold_threshold = 300;
bool selfOscMode = false; // used for led indication only

daisysp::Svf resonantLPF;
daisysp::Svf resonantLPF2;

TapeModulator modTape;

// Synth
static VoiceManager<12> voice_handler;


/////////////////////////// TEST SETTINGS
bool dissonantMode = false;
int dissonant_mode_timer = 500;
int dissonant_mode_timer_threshold = 500;

bool chromaticMode = false;
int chromatic_mode_timer = 500;
int chromatic_mode_timer_threshold = 500;


///////////////////////////



#define MAX_DELAY static_cast<size_t>(4096 * 4.f)
#define MAX_DELAY_REV static_cast<size_t>(4096 * 4.f * 2.f) // Reverse delay must be double normal delay size to have same delay time (read and write heads are going opposite directions)
daisysp::DelayLine<float, MAX_DELAY> delayLine;
daisysp::DelayLine<float, MAX_DELAY> delayLine2;

DelayLineReverse<float, MAX_DELAY_REV> delayLineRev;
DelayLineReverse<float, MAX_DELAY_REV> delayLineRev2;

// NOTE: Not using float to integer conversion on delaylines, enough RAM space due to small buffer sizes so reduction not needed
struct delay
{
    daisysp::DelayLine<float, MAX_DELAY> *del;
    DelayLineReverse<float, MAX_DELAY_REV> *delRev;
    float                        currentDelay;
    float                        delayTarget;
    float                        feedback;
    float                        active = false;
    float                        speed = 1.0;  // range 0 to 1, controlled by knob parameter (put a fonepole for this to add "Glide" function)
    float                        inc_counter = 0;
    float                        current_sample = 0.0;
    float                        currentSpeed;
    bool                         isRight = false;
    bool                         reverseMode = false;

    daisysp::Svf LPF;

    float Process(float in)
    {
        //set delay times
        daisysp::fonepole(currentDelay, delayTarget, .0002f);

        del->SetDelay(currentDelay);
        delRev->SetDelay1(currentDelay * 2);  // Doubling delay time due to read and write heads going in opposite directions


        if (glide_float < 0.05) {
        	currentSpeed = speed;
        } else {
        	daisysp::fonepole(currentSpeed, speed, .001 * (1.0 - glide_float));
        }

    	float wowRate = 0.2f + 2.0f * delayModRate; 
    	float flutterRate = 2.0f + 5.0f * delayModRate;

    	float wowDepth = 2.0f * delayModDepth;
      	float flutterDepth = 2.0f * delayModDepth;

	    modTape.ProcessTapeSpeed(wowRate, flutterRate, wowDepth, flutterDepth, 0.7); 
	    float mod_speed = 0.0;
        if (!isRight) {
    		  mod_speed = modTape.GetTapeSpeedLeft() * 0.01;
        } else {
        	mod_speed = modTape.GetTapeSpeedRight() * 0.01;
        }


        inc_counter += (currentSpeed + mod_speed);

        // Basically a samplerate reducer with no interpolation
        float ampOut = 0.0;
        if (inc_counter >= 1.0) {
            inc_counter -= 1.0;

            if (!reverseMode) {
                current_sample = del->Read();
            } else {
                current_sample = delRev->ReadRev();
            }

            LPF.Process(current_sample);
            ampOut = LPF.Low() * 0.51; // THIS MULTIPLIER IS VERY SENSITIVE TO CREATING FEEDBACK, 0.6 is too much

            if (active) {
                del->Write((feedback * ampOut) + in);
                delRev->Write((feedback * ampOut) + in);
            } else {
                del->Write((feedback * ampOut)); // if not active, don't write any new sound to buffer
                delRev->Write((feedback * ampOut));
            }
        } else {

            LPF.Process(current_sample);  // Still need to process LPF at pedal samplerate 48kHz
            ampOut = LPF.Low() * 0.51;

        }

        return ampOut;
    }
};

delay             delay1;
delay             delay2;



bool knobMoved(float old_value, float new_value)
{
    float tolerance = 0.005;
    if (new_value > (old_value + tolerance) || new_value < (old_value - tolerance)) {
        return true;
    } else {
        return false;
    }
}



void setINT1(int index) {

	switch(index) {

		case 0:

			  delaySpeedMultiplier_int1 = (chromaticMode) ? 0.7492 :   // ChromaticMode: down 5 semitones
										  (dissonantMode) ? 0.39685 : 0.25;  // DissonantMode: Oct+3rd down    Normal: 2 Oct down

			break;
		case 1:

			  delaySpeedMultiplier_int1 = (chromaticMode) ? 0.7937  :  // ChromaticMode: down 4 semitones
										  (dissonantMode) ? 0.5297 : 0.33334;  // DissonantMode: 7th down    Normal: Oct+5th down
			break;
		case 2:

			  delaySpeedMultiplier_int1 = (chromaticMode) ? 0.8409  :  // ChromaticMode: down 3 semitones
										  (dissonantMode) ? 0.5946 : 0.5;  // DissonantMode: 6th down Normal: Oct down
			break;
		case 3:

			  delaySpeedMultiplier_int1 = (chromaticMode) ? 0.8909  :  // ChromaticMode: down 2 semitones
										  (dissonantMode) ? 0.8409 : 0.66667;  // DissonantMode: Minor 3rd down Normal: 5th down
			break;
		case 4:

			  delaySpeedMultiplier_int1 = (chromaticMode) ? 0.9439  :  // ChromaticMode: down 1 semitones
										  (dissonantMode) ? 0.8909 : 0.74915;  // DissonantMode: 2nd down Normal: 4th down
			break;
		case 5:

			  delaySpeedMultiplier_int1 = (chromaticMode) ? 1.0  :  // ChromaticMode: root
										  (dissonantMode) ? 1.0 : 1.0;
			break;
		case 6:

			  delaySpeedMultiplier_int1 = (chromaticMode) ? 1.0595  :  // ChromaticMode: up 1 semitones
										  (dissonantMode) ? 1.12246 : 1.3348;  // DissonantMode: 2nd up   Normal: 4th up
			break;
		case 7:

			  delaySpeedMultiplier_int1 = (chromaticMode) ? 1.1225  :  // ChromaticMode: up 2 semitones
										  (dissonantMode) ? 1.1892 : 1.5;  // DissonantMode: Minor 3rd up  Normal: 5th up
			break;
		case 8:

			  delaySpeedMultiplier_int1 = (chromaticMode) ?  1.1892  :  // ChromaticMode: up 3 semitones
										  (dissonantMode) ? 1.6818 : 2.0;  // DissonantMode: 6th up      Normal: Oct up
			break;
		case 9:

			  delaySpeedMultiplier_int1 = (chromaticMode) ? 1.2599  :  // ChromaticMode: up 4 semitones
										  (dissonantMode) ? 1.8877 : 3.0;  // DissonantMode: 7th up      Normal: Oct + 5th up
			break;
		case 10:

			  delaySpeedMultiplier_int1 = (chromaticMode) ? 1.3348  :  // ChromaticMode: up 5 semitones
										  (dissonantMode) ? 2.5198 : 4.0;  // DissonantMode:  Oct+3rd up   Normal: 2 Oct up
			break;

	}

}


void setINT2(int index) {
	switch(index) {

		case 0:

			  delaySpeedMultiplier_int2 = (chromaticMode) ? 0.7492 :   // ChromaticMode: down 5 semitones
										  (dissonantMode) ? 0.39685 : 0.25;  // DissonantMode: Oct+3rd down    Normal: 2 Oct down

			break;
		case 1:

			  delaySpeedMultiplier_int2 = (chromaticMode) ? 0.7937  :  // ChromaticMode: down 4 semitones
										  (dissonantMode) ? 0.5297 : 0.33334;  // DissonantMode: 7th down    Normal: Oct+5th down
			break;
		case 2:

			  delaySpeedMultiplier_int2 = (chromaticMode) ? 0.8409  :  // ChromaticMode: down 3 semitones
										  (dissonantMode) ? 0.5946 : 0.5;  // DissonantMode: 6th down Normal: Oct down
			break;
		case 3:

			  delaySpeedMultiplier_int2 = (chromaticMode) ? 0.8909  :  // ChromaticMode: down 2 semitones
										  (dissonantMode) ? 0.8409 : 0.66667;  // DissonantMode: Minor 3rd down Normal: 5th down
			break;
		case 4:

			  delaySpeedMultiplier_int2 = (chromaticMode) ? 0.9439  :  // ChromaticMode: down 1 semitones
										  (dissonantMode) ? 0.8909 : 0.74915;  // DissonantMode: 2nd down Normal: 4th down
			break;
		case 5:

			  delaySpeedMultiplier_int2 = (chromaticMode) ? 1.0  :  // ChromaticMode: root
										  (dissonantMode) ? 1.0 : 1.0;
			break;
		case 6:

			  delaySpeedMultiplier_int2 = (chromaticMode) ? 1.0595  :  // ChromaticMode: up 1 semitones
										  (dissonantMode) ? 1.12246 : 1.3348;  // DissonantMode: 2nd up   Normal: 4th up
			break;
		case 7:

			  delaySpeedMultiplier_int2 = (chromaticMode) ? 1.1225  :  // ChromaticMode: up 2 semitones
										  (dissonantMode) ? 1.1892 : 1.5;  // DissonantMode: Minor 3rd up  Normal: 5th up
			break;
		case 8:

			  delaySpeedMultiplier_int2 = (chromaticMode) ?  1.1892  :  // ChromaticMode: up 3 semitones
										  (dissonantMode) ? 1.6818 : 2.0;  // DissonantMode: 6th up      Normal: Oct up
			break;
		case 9:

			  delaySpeedMultiplier_int2 = (chromaticMode) ? 1.2599  :  // ChromaticMode: up 4 semitones
										  (dissonantMode) ? 1.8877 : 3.0;  // DissonantMode: 7th up      Normal: Oct + 5th up
			break;
		case 10:

			  delaySpeedMultiplier_int2 = (chromaticMode) ? 1.3348  :  // ChromaticMode: up 5 semitones
										  (dissonantMode) ? 2.5198 : 4.0;  // DissonantMode:  Oct+3rd up   Normal: 2 Oct up
			break;
	}

}

void updateSwitch1()
{


    if (toggleValues[0] == 0) { 
            leftTogglePosition2 = 0;
            base_stage_multiplier = 1.0;
            sequence_lengths_in_samples[0] = current_base_delay_in_samples * base_stage_multiplier;


    } else if (toggleValues[0] == 2) {
        	leftTogglePosition2 = 2;
            base_stage_multiplier = 0.5;
            sequence_lengths_in_samples[0] = current_base_delay_in_samples * base_stage_multiplier;

    } else {                    
        	leftTogglePosition2 = 1;
            base_stage_multiplier = 0.75;
            sequence_lengths_in_samples[0] = current_base_delay_in_samples * base_stage_multiplier;


    } 


}


void updateSwitch2()
{


    if (toggleValues[1] == 0) { 
            leftTogglePosition = 0;
            int1_stage_multiplier = 1.0;
            sequence_lengths_in_samples[1] = current_base_delay_in_samples * int1_stage_multiplier;

    } else if (toggleValues[1] == 2) {
        	leftTogglePosition = 2;
            int1_stage_multiplier = 0.5;
            sequence_lengths_in_samples[1] = current_base_delay_in_samples * int1_stage_multiplier;

    } else {                    
        	leftTogglePosition = 1;
            int1_stage_multiplier = 0.75;
            sequence_lengths_in_samples[1] = current_base_delay_in_samples * int1_stage_multiplier;

    } 


}


void updateSwitch3() 
{
    // DELAY ///////////////////////
    if (toggleValues[2] == 0) {          
            rightTogglePosition = 0;
            int2_stage_multiplier = 1.0;
            sequence_lengths_in_samples[2] = current_base_delay_in_samples * int2_stage_multiplier;

    } else if (toggleValues[2] == 2) { 
            rightTogglePosition = 2;
            int2_stage_multiplier = 0.5;
            sequence_lengths_in_samples[2] = current_base_delay_in_samples * int2_stage_multiplier;


    } else {
            rightTogglePosition = 1;
            int2_stage_multiplier = 0.75;
            sequence_lengths_in_samples[2] = current_base_delay_in_samples * int2_stage_multiplier;
    }
}


void UpdateButtons()
{
    // (De-)Activate bypass and toggle LED when left footswitch is let go
    if(hw.switches[Funbox::FOOTSWITCH_1].FallingEdge())
    {
        if(!expression_pressed) {
            if (alternateMode) {
                alternateMode = false;
                force_reset = true; // force parameter reset to enforce current knob settings when leaving alternate mode
                led1.Set(1.0f);
            } else {
                bypass = !bypass;
                led1.Set(bypass ? 0.0f : 1.0f);
            }
        }

    } 

    // Toggle Alternate mode by holding down the left footswitch, if not already in alternate mode and not in bypass
    if(hw.switches[Funbox::FOOTSWITCH_1].TimeHeldMs() >= 500 && !alternateMode && !bypass) { 
        alternateMode = true;
        led1.Set(0.5f);  // Dim LED in alternate mode
    }


    // Tap Footswitch Action

    // Check if footswitch is pressed, the debouce wait is done, and the footswitch was previously not pressed (not held)
    if (hw.switches[Funbox::FOOTSWITCH_2].FallingEdge()) { 
        //tap_debounce_wait_timer = 0; // Start bypass wait timer for debouce
        //tap_debounce_reset = 1;      // 1 means footswitch is still held

        // Tap processing

        // If tap has been pressed a second time
        if (tap_timer_on) {
            // Set the base delay time
            //  Set the number of stages (samples) based on minimum possible time / 4 (has to be able to be sped up by 4 for +2 octave)
            //  Then adjust base speed to make the actual delay match the tapped delay time

            if (tap_sample_timer >= 65536) {
                delay1.delayTarget = 16384;
                delay2.delayTarget = 16384;
            } else if  (tap_sample_timer >= 32768) {
                delay1.delayTarget = 8192;
                delay2.delayTarget = 8192;
            } else if  (tap_sample_timer >= 16384) {
                delay1.delayTarget = 4096;
                delay2.delayTarget = 4096;
            } else if  (tap_sample_timer >= 8192) {
                delay1.delayTarget = 2048;
                delay2.delayTarget = 2048;
            //} else if  (tap_sample_timer >= 4096) {
            } else {
                delay1.delayTarget = 1024;
                delay2.delayTarget = 1024;
            } 

            delayBaseSpeed = delay1.delayTarget / tap_sample_timer;
            delay1.speed = delayBaseSpeed;
            delay2.speed = delayBaseSpeed;
            current_base_delay_in_samples = tap_sample_timer;

            tap_sample_timer = 0; // reset the timer for next tap (don't turn the tap_timer_on to false, want to keep waiting for another tap)

            delay_timer = 0;  // reset the delay timer for blinking led

            sequence_timer = 0;
            sequence_stage = 0;

            sequence_lengths_in_samples[0] = current_base_delay_in_samples * base_stage_multiplier;
            sequence_lengths_in_samples[1] = current_base_delay_in_samples * int1_stage_multiplier;
            sequence_lengths_in_samples[2] = current_base_delay_in_samples * int2_stage_multiplier;



        } else {  // Else if this is the first tap
            if (alternateMode) {  // If in alternate mode and left footswitch is pressed, toggle Tap Sequencer Mode (on/off)
                tapSequencerMode = !tapSequencerMode;
            } else {
                if (tapSequencerMode) {  // If in tapSequencerMode, increment the sequence for each tap
                    incrementNextSequence = true;
                } else {                 // Else if in normal tap mode, set first tap
                    tap_timer_on = true;
                }
            }
        }



    }



    // Self oscillation by holding left footswitch
    if (hw.switches[Funbox::FOOTSWITCH_2].TimeHeldMs() >= 300) {
        selfOscMode = true;
    	delay1.feedback = 1.1;
    	delay2.feedback = 1.1;
  

    } else {
        delay1.feedback = delayFeedback;
    	delay2.feedback = delayFeedback;
        selfOscMode = false;
    }


}
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
int main(void)
{
    float samplerate;

    hw.Init();
    samplerate = hw.AudioSampleRate();


    hw.SetAudioBlockSize(48);


    alternateMode = false;

    delayLine.Init();
    delayLineRev.Init();
    delay1.del = &delayLine;
    delay1.delRev = &delayLineRev;
    delay1.delayTarget = 4096; // in samples
    delay1.feedback = 0.5;
    delay1.active = true;     // Default to no delay
    delay1.reverseMode = false;

    delayBaseSpeed = delay1.delayTarget / 24000;
    delay1.speed = 1.0 * delayBaseSpeed;


    delayLine2.Init();
    delayLineRev2.Init();
    delay2.del = &delayLine2;
    delay2.delRev = &delayLineRev2;
    delay2.delayTarget = 4096; // in samples
    delay2.feedback = 0.5;
    delay2.active = true;     // Default to no delay
    delay2.reverseMode = false;

    //delayBaseSpeed = delay2.delayTarget / 24000;
    delay2.speed = 1.0 * delayBaseSpeed;

    resonantLPF.Init(SAMPLING_FREQUENCY_HZ);
    resonantLPF.SetRes(0.8f);
    resonantLPF.SetFreq(10000.0);

    resonantLPF2.Init(SAMPLING_FREQUENCY_HZ);
    resonantLPF2.SetRes(0.8f);
    resonantLPF2.SetFreq(10000.0);

    delay1.LPF.Init(SAMPLING_FREQUENCY_HZ);
    delay1.LPF.SetRes(0.5f);
    delay1.LPF.SetDrive(0.55f);
    delay1.LPF.SetFreq(1300.0f);

    delay2.LPF.Init(SAMPLING_FREQUENCY_HZ);
    delay2.LPF.SetRes(0.5f);
    delay2.LPF.SetDrive(0.55f);
    delay2.LPF.SetFreq(1300.0f);

    delay2.isRight = true; // temporary workaround for stereo modulation

    delayModRate = 0.0;
    delayModDepth = 0.0;

    modTape.Init(SAMPLING_FREQUENCY_HZ);

    voice_handler.Init(SAMPLING_FREQUENCY_HZ);
    voice_handler.SetCutoff(1300.0);



    mix.Init(hw.knob[Funbox::KNOB_1], 0.0f, 1.0f, ::daisy::Parameter::LINEAR);
    Lpf.Init(hw.knob[Funbox::KNOB_2], 0.0f, 1.0f, ::daisy::Parameter::LINEAR);

    regen.Init(hw.knob[Funbox::KNOB_3], 0.0f, 1.0f, ::daisy::Parameter::LINEAR);
    glide.Init(hw.knob[Funbox::KNOB_4], 0.0f, 1.0f, ::daisy::Parameter::LINEAR);

    int1.Init(hw.knob[Funbox::KNOB_5], 0.0f, 1.0f, ::daisy::Parameter::LINEAR);
    int2.Init(hw.knob[Funbox::KNOB_6], 0.0f, 1.0f, ::daisy::Parameter::LINEAR);
    expression.Init(hw.expression, 0.0f, 1.0f, Parameter::LINEAR); 

    // Alternate Parameters
    alternateMode = false;


    force_reset = false;


    switch1[0]= Funbox::SWITCH_1_LEFT;
    switch1[1]= Funbox::SWITCH_1_RIGHT;
    switch2[0]= Funbox::SWITCH_2_LEFT;
    switch2[1]= Funbox::SWITCH_2_RIGHT;
    switch3[0]= Funbox::SWITCH_3_LEFT;
    switch3[1]= Funbox::SWITCH_3_RIGHT;
    dip[0]= Funbox::SWITCH_DIP_1;
    dip[1]= Funbox::SWITCH_DIP_2;
    dip[2]= Funbox::SWITCH_DIP_3;
    dip[3]= Funbox::SWITCH_DIP_4;

    pswitch1[0]= false;
    pswitch1[1]= false;
    pswitch2[0]= false;
    pswitch2[1]= false;
    pswitch3[0]= false;
    pswitch3[1]= false;
    pdip[0]= false;
    pdip[1]= false;
    pdip[2]= false;
    pdip[3]= false;

    update_switches = true;

    // Midi
    for( int i = 0; i < 6; ++i ) 
        midi_control[i] = false;  


    // Init the LEDs and set activate bypass
    led1.Init(hw.seed.GetPin(Funbox::LED_1),false);
    led1.Update();
    bypass = true;

    led2.Init(hw.seed.GetPin(Funbox::LED_2),false);
    led2.Update();


    hw.InitMidi();
    hw.midi.StartReceive();

    hw.StartAdc();
    hw.StartAudio(AudioCallback);
    while(1)
    {
        hw.midi.Listen();
        // Handle MIDI Events
        while(hw.midi.HasEvents()) 
        {
            HandleMidiMessage(hw.midi.PopEvent());
        }

       	System::Delay(100);
    }
}

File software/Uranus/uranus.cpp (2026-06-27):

#include "daisy_petal.h"
#include "daisysp.h"
#include "funbox.h"
#include "granularplayermod.h"
#include "fm_synth_2op.h"
#include "expressionHandler.h"
#include <q/fx/envelope.hpp>

//
// This is a template for creating a pedal on the GuitarML Funbox_v3/Daisy Seed platform.
// You can start from here to fill out your effects processing and controls.
// Allows for Stereo In/Out, 6 knobs, 3 3-way switches, 4 dipswitches, 2 SPST Footswitches, 2 LEDs.
//
// Keith Bloemer 6/12/2024
//

using namespace daisy;
using namespace daisysp;
using namespace funbox;  // This is important for mapping the correct controls to the Daisy Seed on Funbox PCB

// Declare a local daisy_petal for hardware access
DaisyPetal hw;
Parameter grainsize, speed, pitch, mix, feedback, width, expression;
float vpitch1, vpitch2;

float dryMix;
float wetMix;

bool alternateMode;
// Initialize "previous" p values
float pmix, ppitch_raw, pspeed_raw;
float vspeed, vpitch; // These need to be global for alternate funtionality

bool force_reset = false;

bool            bypass;
bool            hold;

bool            pswitch1[2], pswitch2[2], pswitch3[2], pdip[4];
int             switch1[2], switch2[2], switch3[2], dip[4];

float      current_grainsize; //for smoothing the size param

int mode = 0; // Sets the envelope mode with 2nd toggle

#define MAX_SAMPLE static_cast<int>(48000.0 / 2) // 0.5 second sample (delay), continually updating with live audio
#define MAX_SAMPLE_SIZET static_cast<size_t>(MAX_SAMPLE) 
//float DSY_SDRAM_BSS audioSample[MAX_SAMPLE_SIZET];  // Need to initialize this to all 0's
float audioSample[MAX_SAMPLE_SIZET];  


GranularPlayerMod swarm[2];


int sample_index;
bool trigger;
int fade_length;  // fade in/fade out audio sample by this many individual samples
int current_grain_buffer_size;

// synth
Adsr       env_;
bool env_gate_ = false;
// global midi key values for granular synth
float note_ = 0.0;
float velocity_ = 0.0;

// LFO for pitch modulation
Oscillator LFO;
float LFO_depth;

bool first_start=true;

Led led1, led2;

// Midi
bool midi_control[6]; // knobs 0-5
float pknobValues[6];
float knobValues[6];


// Expression
ExpressionHandler expHandler;
bool expression_pressed;

int effect_mode = 0;
int synth_mode = 0;

float led2_brightness = 0.0;

int counter = 0;


// FM Synth
static VoiceManager<12> voice_handler;


bool knobMoved(float old_value, float new_value)
{
    float tolerance = 0.005;
    if (new_value > (old_value + tolerance) || new_value < (old_value - tolerance)) {
        return true;
    } else {
        return false;
    }
}

// Switches1 live mode, sample mode, dry sample loop mode
void updateSwitch1() 
{
    if (pswitch1[0] == true) { 
        effect_mode = 0;
        vpitch1 = 0;
        vpitch2 = 1200;

    } else if (pswitch1[1] == true) {  
        effect_mode = 2;
        vpitch1 = -1200;
        vpitch2 = 1200;

    } else {  
        effect_mode = 1;
        vpitch1 = 0;
        vpitch2 = -1200;
    }   
}

void updateSwitch2() // envelope modes
{
    if (pswitch2[0] == true) {         // left  cosine grain envelope
        mode = 0;
    } else if (pswitch2[1] == true) {  // right   fast attack-decay grain envelope
        mode = 2;
    } else {                           // center  attack- fast decay grain envelope
        mode = 1;
    }

    for (int i = 0; i < 2; i++) {
        swarm[i].setEnvelopeMode(mode);
    }     
}


void updateSwitch3() // left=, center=, right=
{
    if (pswitch3[0] == true) {  // left
        synth_mode = 0;
        

    } else if (pswitch3[1] == true) {  // right
        synth_mode = 2;
        

    } else {   // center
        synth_mode = 1;
    } 

    force_reset = true;   
}


void UpdateButtons()
{

    // (De-)Activate bypass and toggle LED when left footswitch is let go
    if(hw.switches[Funbox::FOOTSWITCH_1].FallingEdge())
    {
        if(!expression_pressed) {
            if (alternateMode) {
                alternateMode = false;
                force_reset = true; // force parameter reset to enforce current knob settings when leaving alternate mode
                led1.Set(1.0f);
            } else {
                bypass = !bypass;
                led1.Set(bypass ? 0.0f : 1.0f);
            }
        }
        expression_pressed = false;
    } 

    // Toggle Alternate mode by holding down the left footswitch, if not already in alternate mode and not in bypass
    if(hw.switches[Funbox::FOOTSWITCH_1].TimeHeldMs() >= 600 && !alternateMode && !bypass && !hw.switches[Funbox::FOOTSWITCH_2].Pressed() && !expression_pressed) {
        alternateMode = true;
        led1.Set(0.5f);  // Dim LED in alternate mode
    }


    // Toggle Expression mode by holding down both footswitches for half a second
    if(hw.switches[Funbox::FOOTSWITCH_1].TimeHeldMs() >= 500 && hw.switches[Funbox::FOOTSWITCH_2].TimeHeldMs() >= 500 && !expression_pressed ) {
        expHandler.ToggleExpressionSetMode();

        if (expHandler.isExpressionSetMode()) {
            led1.Set(expHandler.returnLed1Brightness());  // Dim LEDs in expression set mode
            led2.Set(expHandler.returnLed2Brightness());  // Dim LEDs in expression set mode

        } else {
            led1.Set(bypass ? 0.0f : 1.0f); 
            led2.Set(0.0f);  
        }
        expression_pressed = true; // Keeps it from switching over and over while held
    }


    // Clear Expression settings by holding down both footswitches for 2 seconds
    if(hw.switches[Funbox::FOOTSWITCH_1].TimeHeldMs() >= 2000 && hw.switches[Funbox::FOOTSWITCH_2].TimeHeldMs() >= 2000) {
        expHandler.Reset();
        led1.Set(bypass ? 0.0f : 1.0f); 
        led2.Set(0.0f); 
    }


    // Hold current sample when activated (half led brightness when held)
    if(hw.switches[Funbox::FOOTSWITCH_2].FallingEdge() && !expression_pressed)
    {
        hold = !hold;
        led2.Set(hold ? 1.0 : 0.0);
    }

    led1.Update();
    led2.Update();
}
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

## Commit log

2024-05-01 Added kicad files
    [funbox.kicad_pcb, funbox.kicad_sch, funbox_BOM.csv]
2024-05-17 Added chorusverb, fixes to mars and neptune
    [neptune.cpp]
2024-05-17 Added funbox v2 and v3 kicad files
    [AudioBuffers.kicad_sch, Midi.kicad_sch, Midi_InOut.kicad_sch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]
2024-05-21 Added drill template link
2024-05-21 Added drill template links
2024-05-22 Updated for version 3 pcb
2024-05-30 Updates and fixes to Jupiter and Pluto
    [jupiter.cpp, pluto.cpp]
2024-05-30 Added reverb and filter effects to Pluto
2024-06-09 Updated stability to use smoothrandom
    [pluto.cpp]
2024-06-09 Updated filter
2024-06-15 Updated to version 3.1, fix expression, adjusted pieces
    [Midi.kicad_sch, funbox_v3.kicad_pcb, funbox_v3_BOM.csv]
2024-06-15 Added bksheperd framework definitions
2024-06-17 Updated version2 pcb. Updated expression for Jupiter, Neptune, and Pluto
    [funbox_v2.kicad_pcb]
2024-06-17 Fixed looper led logic when switching out of Set Expression mode
    [pluto.cpp]
2024-06-21 Fixed jupiter params logic
    [jupiter.cpp]
2024-06-21 Fixed neptune switch logic
    [jupiter.cpp, neptune.cpp]
2024-06-21 Fixed neptune switches on start up
    [neptune.cpp]
2024-06-24 Fixed Pluto LED blink, updated neptune reverb mode, updated infographics
    [neptune.cpp, pluto.cpp]
2024-06-24 Fixed bug in switch logic
    [jupiter.cpp]
2024-06-24 Added pF label for clarity
    [funbox_v2.kicad_pcb, funbox_v3.kicad_pcb]
2024-06-25 Fixed midi for Jupiter
    [jupiter.cpp]
2024-06-29 Added gerber files, updated readme
2024-07-13 Updated board to v3.2 to use MCP6024 op amp instead of TL074
    [funbox_v3.kicad_pcb, funbox_v3_BOM.csv]
2024-10-29 Updated bom units
    [funbox_v3_BOM.csv]
2024-11-01 Fixed Bom
    [funbox_v3_BOM.csv]
2024-11-07 Added info to BOM
    [funbox_v3_BOM.csv]
2025-01-10 Staged dependencies and documentation for new modules
2025-01-30 Updated granular experiment, fixed audio sample fading
    [granular.cpp]
2026-06-27 Updated balnea tap led
